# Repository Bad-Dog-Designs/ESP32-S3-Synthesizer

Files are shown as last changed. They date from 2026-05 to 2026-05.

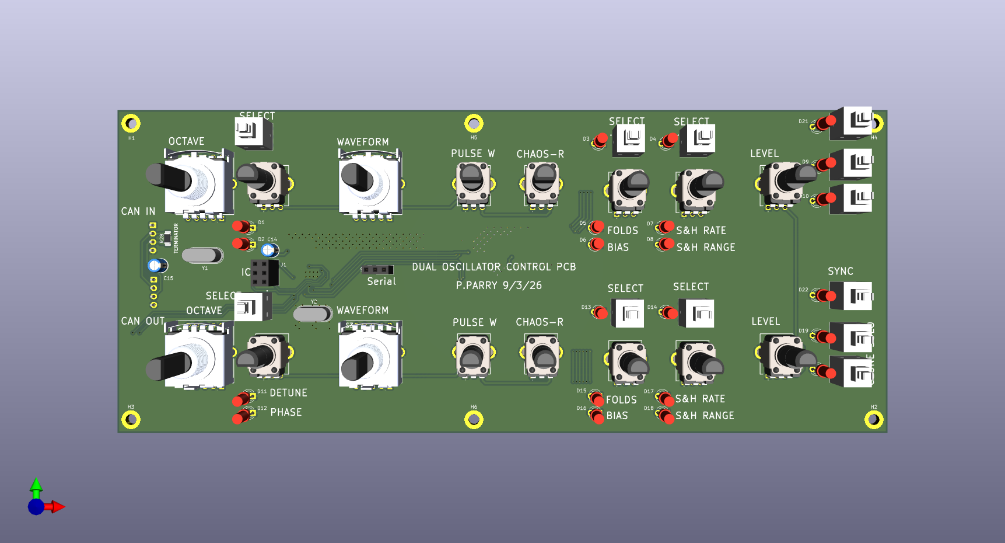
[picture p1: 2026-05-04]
Oscillator_Board/Oscillator_Board.png

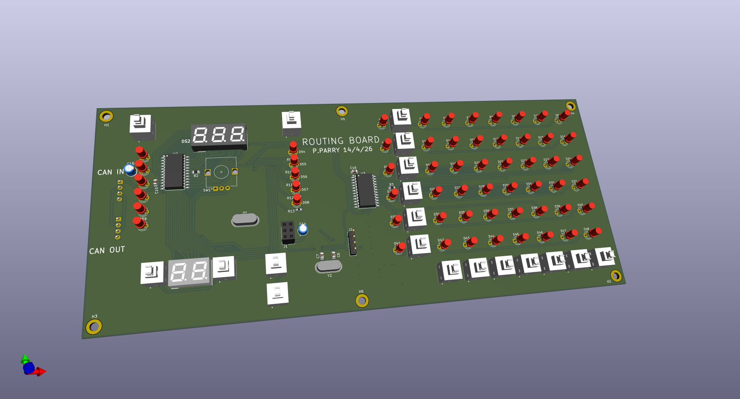
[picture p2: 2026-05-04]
Routing_Board/Routing_Board/Routing_Board.png

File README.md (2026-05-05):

Project overview:
A custom polyphonic synthesizer built around an ESP32-S3 audio engine communicating with multiple ATmega328p control boards via CAN bus at 500kbps. All boards share synth_params.h as the single source of truth for CAN message definitions.
Hardware boards:

ESP32-S3 — audio engine, MIDI input, I2S DAC output, CAN master
Oscillator boards (ATmega328p, up to 4) — dual oscillator control per board, board ID set by hardware jumpers (both open = board 0)
Commons board (ATmega328p) — filter, envelope, LFO, ring mod, play mode controls
Routing board (ATmega328p) — modulation matrix UI, 12 routes, LED matrix display
Patch board (ATmega328p, pending) — SD card patch storage UI, keypad, VFD/starburst display

ESP32-S3 pin assignments:

I2S: GPIO 4(BCK), 5(WS), 6(DOUT)
CAN TX/RX: GPIO 7/8
MIDI RX: GPIO 16
SD card: GPIO 9(CD), 10(CS), 11(MOSI), 12(SCK), 13(MISO)

Current file set (V11.0):

synth_v11.ino — setup(), loop(), task spawn only
synth_engine.h — all type/struct definitions, extern globals, function prototypes
synth_engine.cpp — globals, voice management, oscillator, filter, LFO, FM, audio task
synth_midi.h/.cpp — MIDI byte processing, noteOn/Off, voice allocation
synth_can.h/.cpp — TWAI setup, systemStartup, processCanMessages, sendCanAck
synth_params.h — shared CAN parameter definitions, all boards

Architecture:

Audio runs on Core 1 via audioTask(), CAN+MIDI runs on Core 0 via loop()
portMUX_TYPE voiceMux protects voice array cross-core access
NUM_VOICES_ACTIVE set dynamically from detected oscillator boards at startup (2 per board)
TWAI rx_queue_len=64 to handle full parameter dumps

Voice model:

Up to 8 voices (MAX_VOICES), typically 6 active (3 oscillator boards)
Even voices (0,2,4,6) are FM/sync masters per board pair
Odd voices (1,3,5,7) are FM/sync slaves — can sync to or be FM-modulated by their partner
FM: OSC_A (even) modulates OSC_B (odd) phase. fmEnabled, fmDepth on even voice. fmRatio on odd voice
Hard sync: per-board-pair, not global. syncEnabled only valid on odd voices
Solo: toggle per voice, restricts noteOn to soloed voices only
Clone: copies all timbre params including fmEnabled, fmDepth, fmRatio to all other voices. cloneActive global drives all clone LEDs on all boards simultaneously. Second press clears LEDs, cloned params remain

Signal chain per voice:
S+H → phaseInc | FM phase offset | Oscillator → Wavefold → SVF Filter → × envLevel × level × velocity
Waveforms: SAW, SINE, TRI, PULSE, CHAOS (logistic map), NOISE
Modifiers:

FOLD: post-oscillator waveshaper. foldEnabled, foldAmount (0-1), foldBias (-1 to +1)
S+H: independent pitch randomiser clock. shEnabled, shRate (0.5-40Hz), shRange (1-48 semitones)
FM: fmEnabled, fmDepth (0-1), fmRatio (0.5-8.0)

Play modes: POLY, DUO (half voices per note), UNISON (all voices per note)
Gain scaling by mode: UNISON=1.8f, DUO=2.0f, POLY=4.0f (tuned by ear)
SVF Filter: Low/Band/High pass. cutoffHz, resonance, envAmount (envelope→cutoff), keyTracking. Coefficients updated on each filter parameter change and at noteOn.
Envelope: ADSR. Times stored as float seconds. Coefficients (attackCoeff etc.) computed by updateEnvelopeRates() — must be called at startup and on any time change.
LFOs: 2× LFOs. 4 waveforms (SINE/TRI/CHAOS/S&H). Rate, delay, retrigger. No depth — depth is per-route. RETRIGGER is toggle: each CAN message flips state.
Ring modulator: 4 voice pair options. level, modMute.
Modulation routing (V11 — implementation pending):

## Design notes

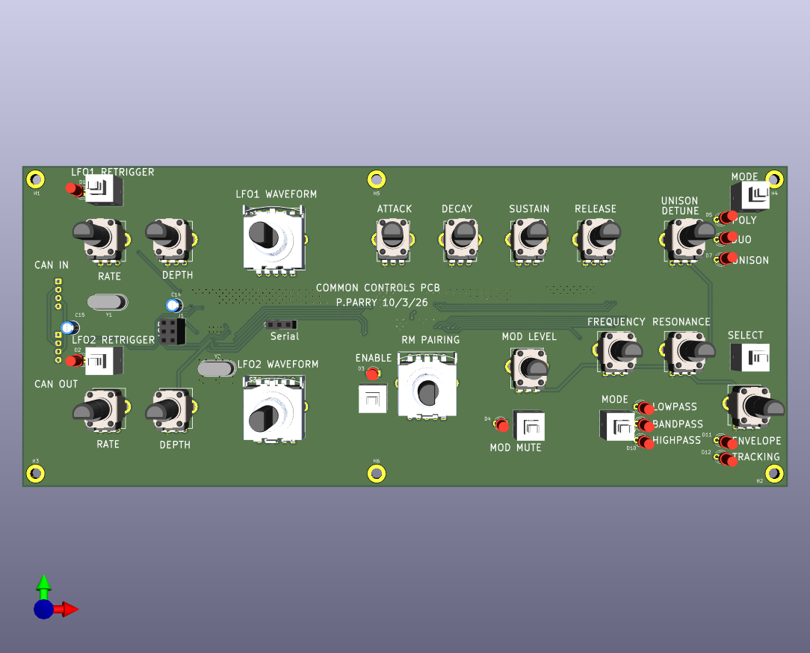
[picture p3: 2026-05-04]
Commons_Board/Commons_Board.png

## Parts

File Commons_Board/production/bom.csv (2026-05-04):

Designator | Footprint | Quantity | Value | LCSC Part #
C1, C2, C6, C7 | 0805 | 4 | 22pf
C10, C11, C3, C4, C5, C8, C9 | 0805 | 7 | 100nF
C12, C13 | 0805 | 2 | 1uF
C14 | CP_Radial_D4.0mm_P2.00mm | 1 | 4.7uF
C15 | CP_Radial_D4.0mm_P2.00mm | 1 | 100uF
C16 | 0805 | 1 | 10nF
D1, D10, D11, D12, D2, D3, D4, D5, D6, D7, D8, D9 | LED_D3.0mm_FlatTop | 12 | LED
FB1 | 0805 | 1 | 10R
IC1 | SOIC127P600X175-8N | 1 | TJA1050T_CM,118
IC2 | SOP65P640X120-20N | 1 | MCP2515T-I_ST
IC3, IC4 | SOIC127P1030X265-28N | 2 | MCP23017-E_SO
J1 | PinSocket_2x03_P2.54mm_Vertical | 1 | ICP Header
J2 | PinSocket_1x03_P2.54mm_Vertical | 1 | Serial Mon
J3 | JST_EH_S4B-EH_1x04_P2.50mm_Horizontal | 1 | Output
J4 | JST_EH_S4B-EH_1x04_P2.50mm_Horizontal | 1 | Input
R1, R25 | 0603 | 2 | 10k
R10, R11, R12, R13, R14, R15, R4, R5, R6, R7, R8, R9 | 0603 | 12 | 330R
R16, R17, R18, R19, R2, R3, R35, R36, R39, R40, R41, R44, R45, R46 | 0603 | 14 | 4k7
R24, R53 | 0603 | 2 | 1k
R28 | 1206 | 1 | 120R
S1 | SR1712F010820F0AN9N027 | 1 | Waveform_0
S10, S11, S5, S6, S7, S8, S9 | TL2285OA | 7 | TL2285OA
S2 | SR1712F010820F0AN9N027 | 1 | Range_0
S3 | SR1712F010820F0AN9N027 | 1 | Waveform_1
U1 | TQFP-32_7x7mm_P0.8mm | 1 | ATmega328P-A
U2 | SSOP-24_5.3x8.2mm_P0.65mm | 1 | CD74HC4067SM
VR1 | RK09K1130AAU | 1 | LFO1_Rate
VR10 | RK09K1130AAU | 1 | Frequency
VR11 | RK09K1130AAU | 1 | Resonance
VR12 | RK09K1130AAU | 1 | Env_Track
VR13 | RK09K1130AAU | 1 | Detune
VR2 | RK09K1130AAU | 1 | LFO1_Depth
VR3 | RK09K1130AAU | 1 | LFO2_Rate
VR4 | RK09K1130AAU | 1 | LFO2_Depth
VR5 | RK09K1130AAU | 1 | Mod_Level
VR6 | RK09K1130AAU | 1 | Attack
VR7 | RK09K1130AAU | 1 | Decay
VR8 | RK09K1130AAU | 1 | Sustain
VR9 | RK09K1130AAU | 1 | Release
Y1 | Crystal_HC49-4H_Vertical | 1 | 8Mhz
Y2 | Crystal_HC49-4H_Vertical | 1 | 16Mhz

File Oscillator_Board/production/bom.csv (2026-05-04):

Designator | Footprint | Quantity | Value | LCSC Part #
C1, C2, C6, C7 | 0805 | 4 | 22pf
C10, C11, C3, C4, C5, C8, C9 | 0805 | 7 | 100nF
C12, C13 | 0805 | 2 | 1uF
C14 | CP_Radial_D4.0mm_P2.00mm | 1 | 4.7uF
C15 | CP_Radial_D4.0mm_P2.00mm | 1 | 100uF
C16 | 0805 | 1 | 10nF
D1, D10, D11, D12, D13, D14, D15, D16, D17, D18, D19, D2, D20, D21, D22, D3, D4, D5, D6, D7, D8, D9 | LED_D3.0mm_FlatTop | 22 | LED
FB1 | 0805 | 1 | 10R
IC1 | SOIC127P600X175-8N | 1 | TJA1050T_CM,118
IC2 | SOP65P640X120-20N | 1 | MCP2515T-I_ST
IC3, IC4 | SOIC127P1030X265-28N | 2 | MCP23017-E_SO
J1 | PinSocket_2x03_P2.54mm_Vertical | 1 | ICP Header
J2 | PinSocket_1x03_P2.54mm_Vertical | 1 | Serial Mon
J3 | JST_EH_S4B-EH_1x04_P2.50mm_Horizontal | 1 | Output
J4 | JST_EH_S4B-EH_1x04_P2.50mm_Horizontal | 1 | Input
R1, R25, R29, R30 | 0603 | 4 | 10k
R10, R11, R12, R13, R14, R15, R16, R17, R18, R19, R20, R21, R22, R23, R26, R27, R4, R5, R6, R7, R8, R9 | 0603 | 22 | 330R
R2, R3, R35, R36, R37, R38, R39, R40, R41, R42, R43, R44, R45, R46, R47, R48, R49, R50, R51, R52 | 0603 | 20 | 4k7
R24, R53 | 0603 | 2 | 1k
R28 | 1206 | 1 | 120R
R31, R32, R33, R34 | 0603 | 4 | Link
S1 | SR1712F010820F0AN9N027 | 1 | Waveform_0
S10, S11, S12, S13, S14, S15, S16, S5, S6, S7, S8, S9 | TL2285OA | 12 | TL2285OA
S2 | SR1712F010820F0AN9N027 | 1 | Range_0
S3 | SR1712F010820F0AN9N027 | 1 | Waveform_1
S4 | SR1712F010820F0AN9N027 | 1 | Range_1
U1 | TQFP-32_7x7mm_P0.8mm | 1 | ATmega328P-A
U2 | SSOP-24_5.3x8.2mm_P0.65mm | 1 | CD74HC4067SM
VR1, VR7 | RK09K1130AAU | 2 | Detune_1
VR10, VR4 | RK09K1130AAU | 2 | Folds_1
VR11, VR5 | RK09K1130AAU | 2 | S&H_1
VR12, VR6 | RK09K1130AAU | 2 | Level_1
VR2, VR8 | RK09K1130AAU | 2 | PulseW_1
VR3, VR9 | RK09K1130AAU | 2 | ChaosR_1
Y1 | Crystal_HC49-4H_Vertical | 1 | 8Mhz
Y2 | Crystal_HC49-4H_Vertical | 1 | 16Mhz

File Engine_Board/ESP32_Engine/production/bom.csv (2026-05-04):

Designator | Footprint | Quantity | Value | LCSC Part #
C1, C10, C16, C18, C2, C23, C6 | 0603 | 7 | 100nF
C11, C12 | 0603 | 2 | 2.2nF
C13, C14 | 0805 | 2 | 2.2uF
C15 | CP_Radial_D4.0mm_P2.00mm | 1 | 100uF
C17, C19, C5, C7 | 0805 | 4 | 10uF
C20 | CP_Radial_D4.0mm_P2.00mm | 1 | 4u7
C21, C22, C8, C9 | 0805 | 4 | 100nF
C3, C4 | 0805 | 2 | 2u2
D1 | D_MELF | 1 | 1N4148
IC2 | SOP65P640X120-20N | 1 | PCM5102AQPWRQ1
IC3 | SOT95P280X100-5N | 1 | 3v3 Digital Reg
IC4 | SOT95P280X100-5N | 1 | 3v3 Analogue Reg
J1 | 5033981892 | 1 | 503398-1892
J2 | Midi_Socket | 1 | Midi in
J3 | JST_EH_S4B-EH_1x04_P2.50mm_Horizontal | 1 | Output
J4 | JST_EH_S4B-EH_1x04_P2.50mm_Horizontal | 1 | Input
J5 | Jack_3.5mm_CUI_SJ1-3533NG_Horizontal | 1 | AudioJack3
R1, R2, R3 | 0603 | 3 | 22R
R10, R6, R7, R8, R9 | 0603 | 5 | 10k
R11 | 0603 | 1 | 220R
R12, R4, R5 | 0603 | 3 | 470R
R28 | 0603 | 1 | 120R
U1 | ESP32_S3 | 1 | ESP32-S3
U2 | DIP-8_W7.62mm | 1 | MCP2562-H-P
U3 | DIP-6_W7.62mm_SMDSocket_SmallPads | 1 | H11L1

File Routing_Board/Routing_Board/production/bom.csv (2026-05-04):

Designator | Footprint | Quantity | Value | LCSC Part #
C1, C2, C6, C7 | 0805 | 4 | 22pf
C10, C11, C16, C3, C4, C5, C8, C9 | 0805 | 8 | 100nF
C12, C13 | 0805 | 2 | 1uF
C14 | CP_Radial_D4.0mm_P2.00mm | 1 | 4.7uF
C15 | CP_Radial_D4.0mm_P2.00mm | 1 | 100uF
D1, D10, D11, D12, D13, D14, D15, D16, D17, D18, D19, D2, D20, D21, D22, D23, D24, D25, D26, D27, D28, D29, D3, D30, D31, D32, D33, D34, D35, D36, D37, D38, D39, D4, D40, D41, D42, D43, D44, D45, D46, D47, D48, D49, D5, D50, D51, D52, D53, D54, D55, D56, D57, D58, D59, D6, D7, D8, D9 | LED_D3.0mm_FlatTop | 59 | LED
DS1 | DIPS762W50P254L1502H635Q10N | 1 | LTD-2701JD
DS2 | DIPS762W45P254L2253H610Q12N | 1 | LDT-N2804RI
IC1 | SOIC127P600X175-8N | 1 | TJA1050T_CM,118
IC2 | SOP65P640X120-20N | 1 | MCP2515T-I_ST
IC3, IC4 | SOIC127P1030X265-28N | 2 | MCP23017-E_SO
J1 | PinSocket_2x03_P2.54mm_Vertical | 1 | ICP Header
J2 | PinHeader_1x04_P2.54mm_Vertical | 1 | Diagnostic
J3 | JST_EH_S4B-EH_1x04_P2.50mm_Horizontal | 1 | Output
J4 | JST_EH_S4B-EH_1x04_P2.50mm_Horizontal | 1 | Input
R1, R25 | 0603 | 2 | 10k
R10, R11, R12, R13, R18, R4, R5, R6, R7, R8, R9 | 0603 | 11 | 330R
R14, R15 | 0805 | 2 | 10k
R16, R17 | 0805 | 2 | 4k7
R2, R3 | 0805 | 2 | 22k
R24 | 0603 | 1 | 1k
R28 | 1206 | 1 | 120R
S1, S10, S11, S12, S13, S14, S15, S16, S17, S18, S19, S2, S3, S4, S5, S6, S7, S8, S9 | TL2285OA | 19 | TL2285OA
SW1 | RotaryEncoder_Alps_EC12E_Vertical_H20mm | 1 | RotaryEncoder
U1 | TQFP-32_7x7mm_P0.8mm | 1 | ATmega328P-A
U2, U3 | SOIC-24W_7.5x15.4mm_P1.27mm | 2 | MAX7219
Y1 | Crystal_HC49-4H_Vertical | 1 | 8Mhz
Y2 | Crystal_HC49-4H_Vertical | 1 | 16Mhz

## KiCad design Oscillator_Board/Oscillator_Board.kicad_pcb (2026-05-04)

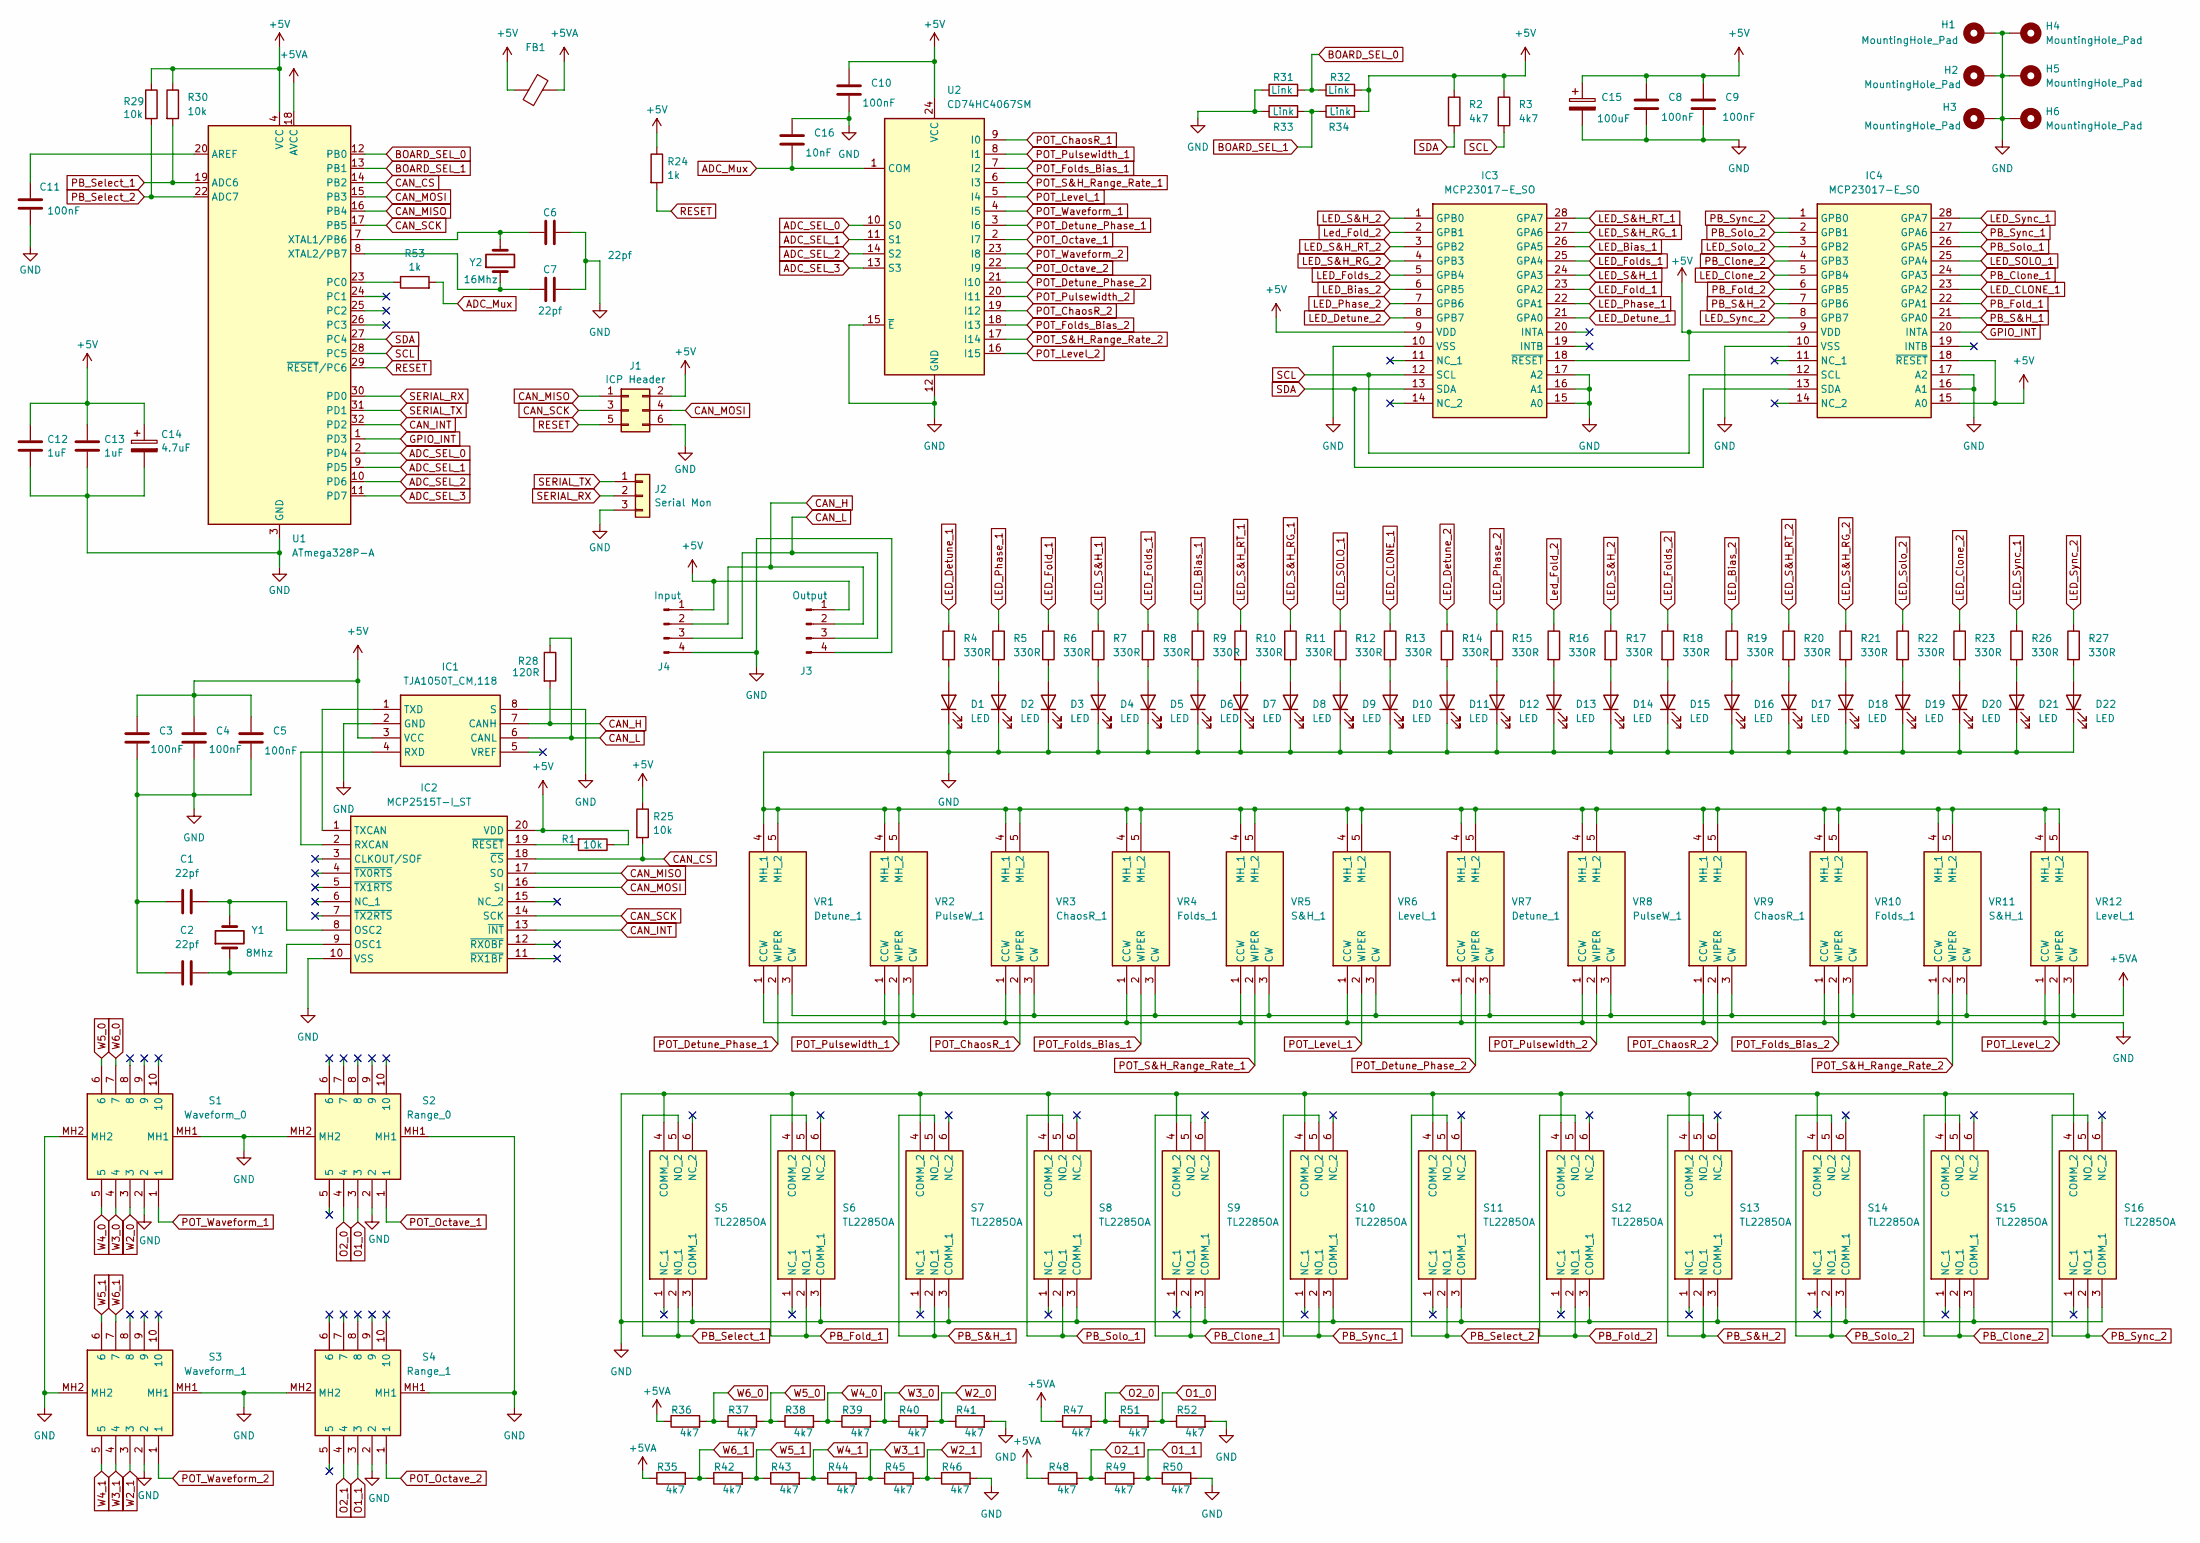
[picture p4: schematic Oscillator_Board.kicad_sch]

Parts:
C1, C2, C6, C7: 22pf; C_0805_2012Metric_Pad1.18x1.45mm_HandSolder
C3, C4, C5, C8, C9, C10, C11: 100nF; C_0805_2012Metric_Pad1.18x1.45mm_HandSolder
C12, C13: 1uF; C_0805_2012Metric_Pad1.18x1.45mm_HandSolder
C14: 4.7uF; CP_Radial_D4.0mm_P2.00mm
C15: 100uF; CP_Radial_D4.0mm_P2.00mm
C16: 10nF; C_0805_2012Metric_Pad1.18x1.45mm_HandSolder
D1, D2, D3, D4, D5, D6, D7, D8, D9, D10, D11, D12, D13, D14, D15, D16, D17, D18, D19, D20, D21, D22: LED; LED_D3.0mm_FlatTop
FB1: 10R; R_0805_2012Metric_Pad1.20x1.40mm_HandSolder
H1, H2, H3, H4, H5, H6: MountingHole_Pad; MountingHole_3.2mm_M3_DIN965_Pad
IC1: TJA1050T_CM,118; SOIC127P600X175-8N; Mouser Part Number 771-TJA1050T/CM118
IC2: MCP2515T-I_ST; SOP65P640X120-20N; Mouser Part Number 579-MCP2515T-I/ST
IC3, IC4: MCP23017-E_SO; SOIC127P1030X265-28N; Mouser Part Number 579-MCP23017-E/SO
J1: ICP Header; PinSocket_2x03_P2.54mm_Vertical
J2: Serial Mon; PinSocket_1x03_P2.54mm_Vertical
J3: Output; JST_EH_S4B-EH_1x04_P2.50mm_Horizontal
J4: Input; JST_EH_S4B-EH_1x04_P2.50mm_Horizontal
R1, R25, R29, R30: 10k; R_0603_1608Metric_Pad0.98x0.95mm_HandSolder
R2, R3, R35, R36, R37, R38, R39, R40, R41, R42, R43, R44, R45, R46, R47, R48, R49, R50, R51, R52: 4k7; R_0603_1608Metric_Pad0.98x0.95mm_HandSolder
R4, R5, R6, R7, R8, R9, R10, R11, R12, R13, R14, R15, R16, R17, R18, R19, R20, R21, R22, R23, R26, R27: 330R; R_0603_1608Metric_Pad0.98x0.95mm_HandSolder
R24, R53: 1k; R_0603_1608Metric_Pad0.98x0.95mm_HandSolder
R28: 120R; R_1206_3216Metric_Pad1.30x1.75mm_HandSolder
R31, R32, R33, R34: Link; R_0603_1608Metric_Pad0.98x0.95mm_HandSolder
S1: Waveform_0; SR1712F010820F0AN9N027; Mouser Part Number 105-SR1712F-18NS
S2: Range_0; SR1712F010820F0AN9N027; Mouser Part Number 105-SR1712F-18NS
S3: Waveform_1; SR1712F010820F0AN9N027; Mouser Part Number 105-SR1712F-18NS
S4: Range_1; SR1712F010820F0AN9N027; Mouser Part Number 105-SR1712F-18NS
S5, S6, S7, S8, S9, S10, S11, S12, S13, S14, S15, S16: TL2285OA; Mouser Part Number 612-TL2285OA
U1: ATmega328P-A; TQFP-32_7x7mm_P0.8mm
U2: CD74HC4067SM; SSOP-24_5.3x8.2mm_P0.65mm
VR1, VR7: Detune_1; RK09K1130AAU; Mouser Part Number 688-RK09K1130AAU
VR2, VR8: PulseW_1; RK09K1130AAU; Mouser Part Number 688-RK09K1130AAU
VR3, VR9: ChaosR_1; RK09K1130AAU; Mouser Part Number 688-RK09K1130AAU
VR4, VR10: Folds_1; RK09K1130AAU; Mouser Part Number 688-RK09K1130AAU
VR5, VR11: S&H_1; RK09K1130AAU; Mouser Part Number 688-RK09K1130AAU
VR6, VR12: Level_1; RK09K1130AAU; Mouser Part Number 688-RK09K1130AAU
Y1: 8Mhz; Crystal_HC49-4H_Vertical
Y2: 16Mhz; Crystal_HC49-4H_Vertical

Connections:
+5V: C3.1, C4.1, C5.1, C8.1, C9.1, C10.1, C12.1, C13.1, C14.1, C15.1, FB1.1, IC1.3 (VCC), IC2.20 (VDD), IC3.9 (VDD), IC3.18 (~RESET), IC4.9 (VDD), IC4.15 (A0), IC4.18 (~RESET), J1.2, J3.1, J4.1, R1.1, R2.1, R3.1, R24.1, R25.1, R29.1, R30.1, R32.2, R34.2, U1.4 (VCC), U1.6 (VCC), U2.24 (VCC)
+5VA: FB1.2, R35.1, R36.1, R47.1, R48.1, U1.18 (AVCC), VR1.3 (CW), VR2.3 (CW), VR3.3 (CW), VR4.3 (CW), VR5.3 (CW), VR6.3 (CW), VR7.3 (CW), VR8.3 (CW), VR9.3 (CW), VR10.3 (CW), VR11.3 (CW), VR12.3 (CW)
ADC_Mux: C16.2, R53.2, U2.1 (COM)
ADC_SEL_0: U1.2 (PD4), U2.10 (S0)
ADC_SEL_1: U1.9 (PD5), U2.11 (S1)
ADC_SEL_2: U1.10 (PD6), U2.14 (S2)
ADC_SEL_3: U1.11 (PD7), U2.13 (S3)
BOARD_SEL_0: R31.2, R32.1, U1.12 (PB0)
BOARD_SEL_1: R33.2, R34.1, U1.13 (PB1)
CAN_CS: IC2.18 (~CS), R25.2, U1.14 (PB2)
CAN_H: IC1.7 (CANH), J3.2, J4.2, R28.2
CAN_INT: IC2.13 (~INT), U1.32 (PD2)
CAN_L: IC1.6 (CANL), J3.3, J4.3, R28.1
CAN_MISO: IC2.17 (SO), J1.1, U1.16 (PB4)
CAN_MOSI: IC2.16 (SI), J1.4, U1.15 (PB3)
CAN_SCK: IC2.14 (SCK), J1.3, U1.17 (PB5)
GND: C1.1, C2.1, C3.2, C4.2, C5.2, C6.2, C7.2, C8.2, C9.2, C10.2, C11.2, C12.2, C13.2, C14.2, C15.2, C16.1, D1.1 (K), D2.1 (K), D3.1 (K), D4.1 (K), D5.1 (K), D6.1 (K), D7.1 (K), D8.1 (K), D9.1 (K), D10.1 (K), D11.1 (K), D12.1 (K), D13.1 (K), D14.1 (K), D15.1 (K), D16.1 (K), D17.1 (K), D18.1 (K), D19.1 (K), D20.1 (K), D21.1 (K), D22.1 (K), H1.1, H2.1, H3.1, H4.1, H5.1, H6.1, IC1.2 (GND), IC1.8 (S), IC2.10 (VSS), IC3.10 (VSS), IC3.15 (A0), IC3.16 (A1), IC3.17 (A2), IC4.10 (VSS), IC4.16 (A1), IC4.17 (A2), J1.6, J2.3, J3.4, J4.4, R31.1, R33.1, R41.2, R46.2, R50.2, R52.2, S1.2, S1.MH1, S1.MH2, S2.2, S2.MH1, S2.MH2, S3.2, S3.MH1, S3.MH2, S4.2, S4.MH1, S4.MH2, S5.3 (COMM_1), S5.4 (COMM_2), S6.3 (COMM_1), S6.4 (COMM_2), S7.3 (COMM_1), S7.4 (COMM_2), S8.3 (COMM_1), S8.4 (COMM_2), S9.3 (COMM_1), S9.4 (COMM_2), S10.3 (COMM_1), S10.4 (COMM_2), S11.3 (COMM_1), S11.4 (COMM_2), S12.3 (COMM_1), S12.4 (COMM_2), S13.3 (COMM_1), S13.4 (COMM_2), S14.3 (COMM_1), S14.4 (COMM_2), S15.3 (COMM_1), S15.4 (COMM_2), S16.3 (COMM_1), S16.4 (COMM_2), U1.3 (GND), U1.5 (GND), U1.21 (GND), U2.12 (GND), U2.15 (~E), VR1.1 (CCW), VR1.4 (MH_1), VR1.5 (MH_2), VR2.1 (CCW), VR2.4 (MH_1), VR2.5 (MH_2), VR3.1 (CCW), VR3.4 (MH_1), VR3.5 (MH_2), VR4.1 (CCW), VR4.4 (MH_1), VR4.5 (MH_2), VR5.1 (CCW), VR5.4 (MH_1), VR5.5 (MH_2), VR6.1 (CCW), VR6.4 (MH_1), VR6.5 (MH_2), VR7.1 (CCW), VR7.4 (MH_1), VR7.5 (MH_2), VR8.1 (CCW), VR8.4 (MH_1), VR8.5 (MH_2), VR9.1 (CCW), VR9.4 (MH_1), VR9.5 (MH_2), VR10.1 (CCW), VR10.4 (MH_1), VR10.5 (MH_2), VR11.1 (CCW), VR11.4 (MH_1), VR11.5 (MH_2), VR12.1 (CCW), VR12.4 (MH_1), VR12.5 (MH_2)
GPIO_INT: IC4.20 (INTA), U1.1 (PD3)
LED_Bias_1: IC3.26 (GPA5), R9.1
LED_Bias_2: IC3.6 (GPB5), R19.1
LED_CLONE_1: IC4.23 (GPA2), R13.1
LED_Clone_2: IC4.5 (GPB4), R23.1
LED_Detune_1: IC3.21 (GPA0), R4.1
LED_Detune_2: IC3.8 (GPB7), R14.1
LED_Fold_1: IC3.23 (GPA2), R6.1
LED_Folds_1: IC3.25 (GPA4), R8.1
LED_Folds_2: IC3.5 (GPB4), R18.1
LED_Phase_1: IC3.22 (GPA1), R5.1
LED_Phase_2: IC3.7 (GPB6), R15.1
LED_S&H_1: IC3.24 (GPA3), R7.1
LED_S&H_2: IC3.1 (GPB0), R17.1
LED_S&H_RG_1: IC3.27 (GPA6), R11.1
LED_S&H_RG_2: IC3.4 (GPB3), R21.1
LED_S&H_RT_1: IC3.28 (GPA7), R10.1
LED_S&H_RT_2: IC3.3 (GPB2), R20.1
LED_SOLO_1: IC4.25 (GPA4), R12.1
LED_Solo_2: IC4.3 (GPB2), R22.1
LED_Sync_1: IC4.28 (GPA7), R26.1
LED_Sync_2: IC4.8 (GPB7), R27.1
Led_Fold_2: IC3.2 (GPB1), R16.1
unnamed: D1.2 (A), R4.2
unnamed: D2.2 (A), R5.2
unnamed: D3.2 (A), R6.2
unnamed: D4.2 (A), R7.2
unnamed: D5.2 (A), R8.2
unnamed: D6.2 (A), R9.2
unnamed: D7.2 (A), R10.2
unnamed: D8.2 (A), R11.2
unnamed: D9.2 (A), R12.2
unnamed: D10.2 (A), R13.2
unnamed: D11.2 (A), R14.2
unnamed: D12.2 (A), R15.2
unnamed: D13.2 (A), R16.2
unnamed: D14.2 (A), R17.2
unnamed: D15.2 (A), R18.2
unnamed: D16.2 (A), R19.2
unnamed: D17.2 (A), R20.2
unnamed: D18.2 (A), R21.2
unnamed: D19.2 (A), R22.2
unnamed: D20.2 (A), R23.2
unnamed: D21.2 (A), R26.2
unnamed: D22.2 (A), R27.2
unnamed: IC1.4 (RXD), IC2.2 (RXCAN)
unnamed: IC1.1 (TXD), IC2.1 (TXCAN)
unnamed: C2.2, IC2.9 (OSC1), Y1.1
unnamed: C1.2, IC2.8 (OSC2), Y1.2
unnamed: IC2.19 (~RESET), R1.2
unnamed: C11.1, U1.20 (AREF)
unnamed: R53.1, U1.23 (PC0)
unnamed: C6.1, U1.7 (XTAL1/PB6), Y2.2
unnamed: C7.1, U1.8 (XTAL2/PB7), Y2.1
O1_0: R51.2, R52.1, S2.3
O1_1: R49.2, R50.1, S4.3
O2_0: R47.2, R51.1, S2.4
O2_1: R48.2, R49.1, S4.4
PB_Clone_1: IC4.24 (GPA3), S9.2 (NO_1), S9.5 (NO_2)
PB_Clone_2: IC4.4 (GPB3), S15.2 (NO_1), S15.5 (NO_2)
PB_Fold_1: IC4.22 (GPA1), S6.2 (NO_1), S6.5 (NO_2)
PB_Fold_2: IC4.6 (GPB5), S12.2 (NO_1), S12.5 (NO_2)
PB_S&H_1: IC4.21 (GPA0), S7.2 (NO_1), S7.5 (NO_2)
PB_S&H_2: IC4.7 (GPB6), S13.2 (NO_1), S13.5 (NO_2)
PB_Select_1: R30.2, S5.2 (NO_1), S5.5 (NO_2), U1.19 (ADC6)
PB_Select_2: R29.2, S11.2 (NO_1), S11.5 (NO_2), U1.22 (ADC7)
PB_Solo_1: IC4.26 (GPA5), S8.2 (NO_1), S8.5 (NO_2)
PB_Solo_2: IC4.2 (GPB1), S14.2 (NO_1), S14.5 (NO_2)
PB_Sync_1: IC4.27 (GPA6), S10.2 (NO_1), S10.5 (NO_2)
PB_Sync_2: IC4.1 (GPB0), S16.2 (NO_1), S16.5 (NO_2)
POT_ChaosR_1: U2.9 (I0), VR3.2 (WIPER)
POT_ChaosR_2: U2.19 (I12), VR9.2 (WIPER)
POT_Detune_Phase_1: U2.3 (I6), VR1.2 (WIPER)
POT_Detune_Phase_2: U2.21 (I10), VR7.2 (WIPER)
POT_Folds_Bias_1: U2.7 (I2), VR4.2 (WIPER)
POT_Folds_Bias_2: U2.18 (I13), VR10.2 (WIPER)
POT_Level_1: U2.5 (I4), VR6.2 (WIPER)
POT_Level_2: U2.16 (I15), VR12.2 (WIPER)
POT_Octave_1: S2.1, U2.2 (I7)
POT_Octave_2: S4.1, U2.22 (I9)
POT_Pulsewidth_1: U2.8 (I1), VR2.2 (WIPER)
POT_Pulsewidth_2: U2.20 (I11), VR8.2 (WIPER)
POT_S&H_Range_Rate_1: U2.6 (I3), VR5.2 (WIPER)
POT_S&H_Range_Rate_2: U2.17 (I14), VR11.2 (WIPER)
POT_Waveform_1: S1.1, U2.4 (I5)
POT_Waveform_2: S3.1, U2.23 (I8)
RESET: J1.5, R24.2, U1.29 (~RESET/PC6)
SCL: IC3.12 (SCL), IC4.12 (SCL), R3.2, U1.28 (PC5)
SDA: IC3.13 (SDA), IC4.13 (SDA), R2.2, U1.27 (PC4)
SERIAL_RX: J2.2, U1.30 (PD0)
SERIAL_TX: J2.1, U1.31 (PD1)
W2_0: R40.2, R41.1, S1.3
W2_1: R45.2, R46.1, S3.3
W3_0: R39.2, R40.1, S1.4
W3_1: R44.2, R45.1, S3.4
W4_0: R38.2, R39.1, S1.5
W4_1: R43.2, R44.1, S3.5
W5_0: R37.2, R38.1, S1.6
W5_1: R42.2, R43.1, S3.6
W6_0: R36.2, R37.1, S1.7
W6_1: R35.2, R42.1, S3.7

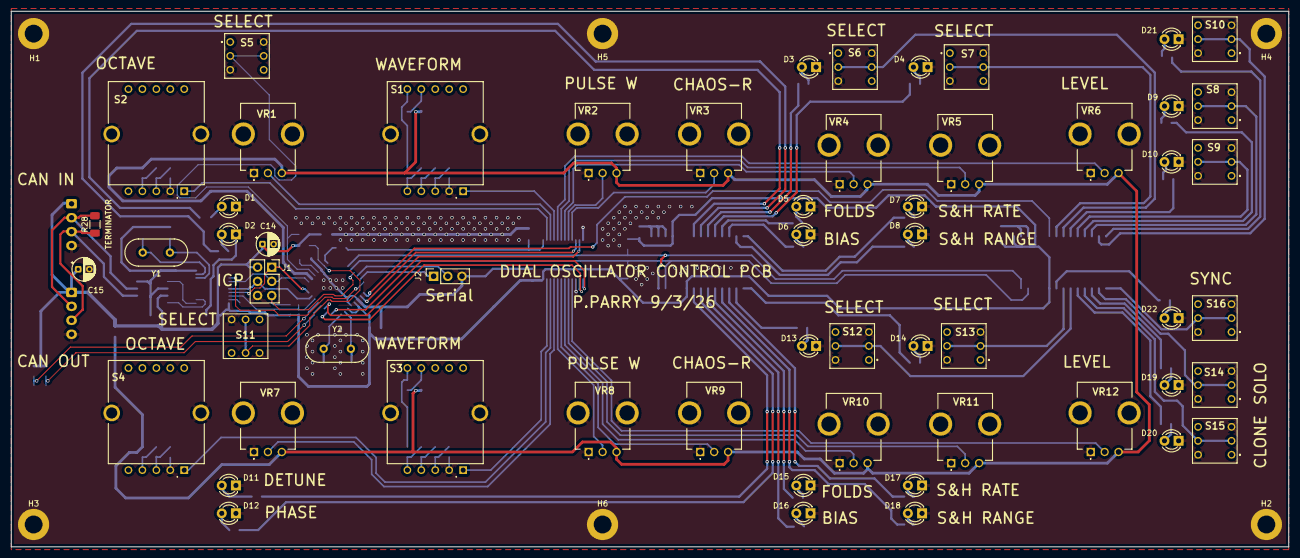
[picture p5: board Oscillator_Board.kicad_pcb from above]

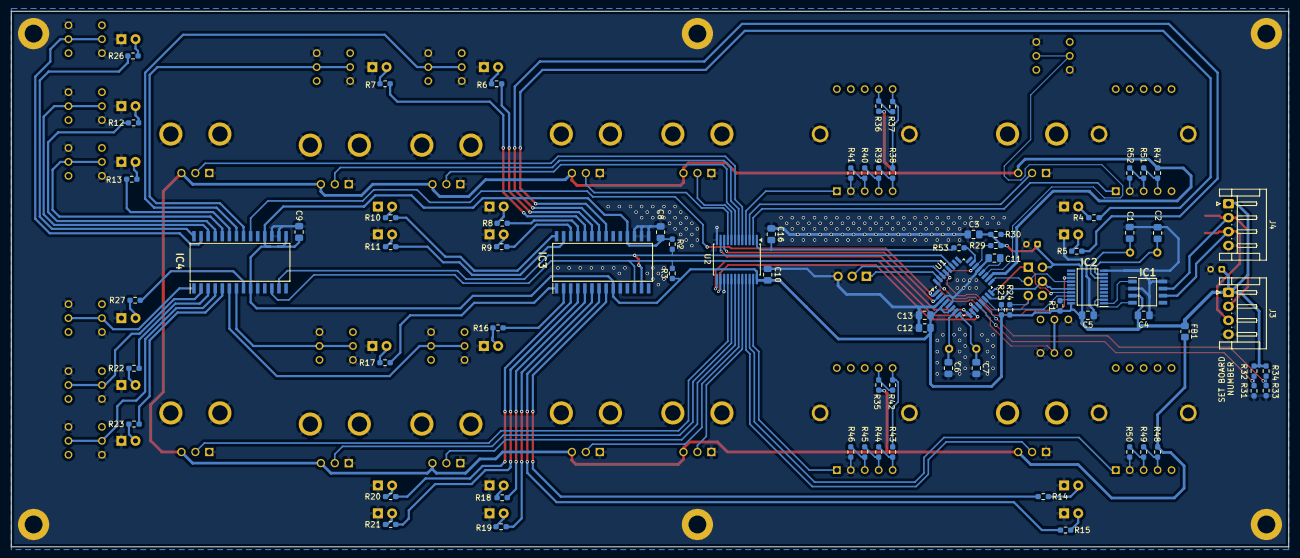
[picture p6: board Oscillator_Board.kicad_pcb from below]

Board: 2 copper layers, 229.0 x 96.0 mm, 138 parts (75 on the bottom side), 118 nets.

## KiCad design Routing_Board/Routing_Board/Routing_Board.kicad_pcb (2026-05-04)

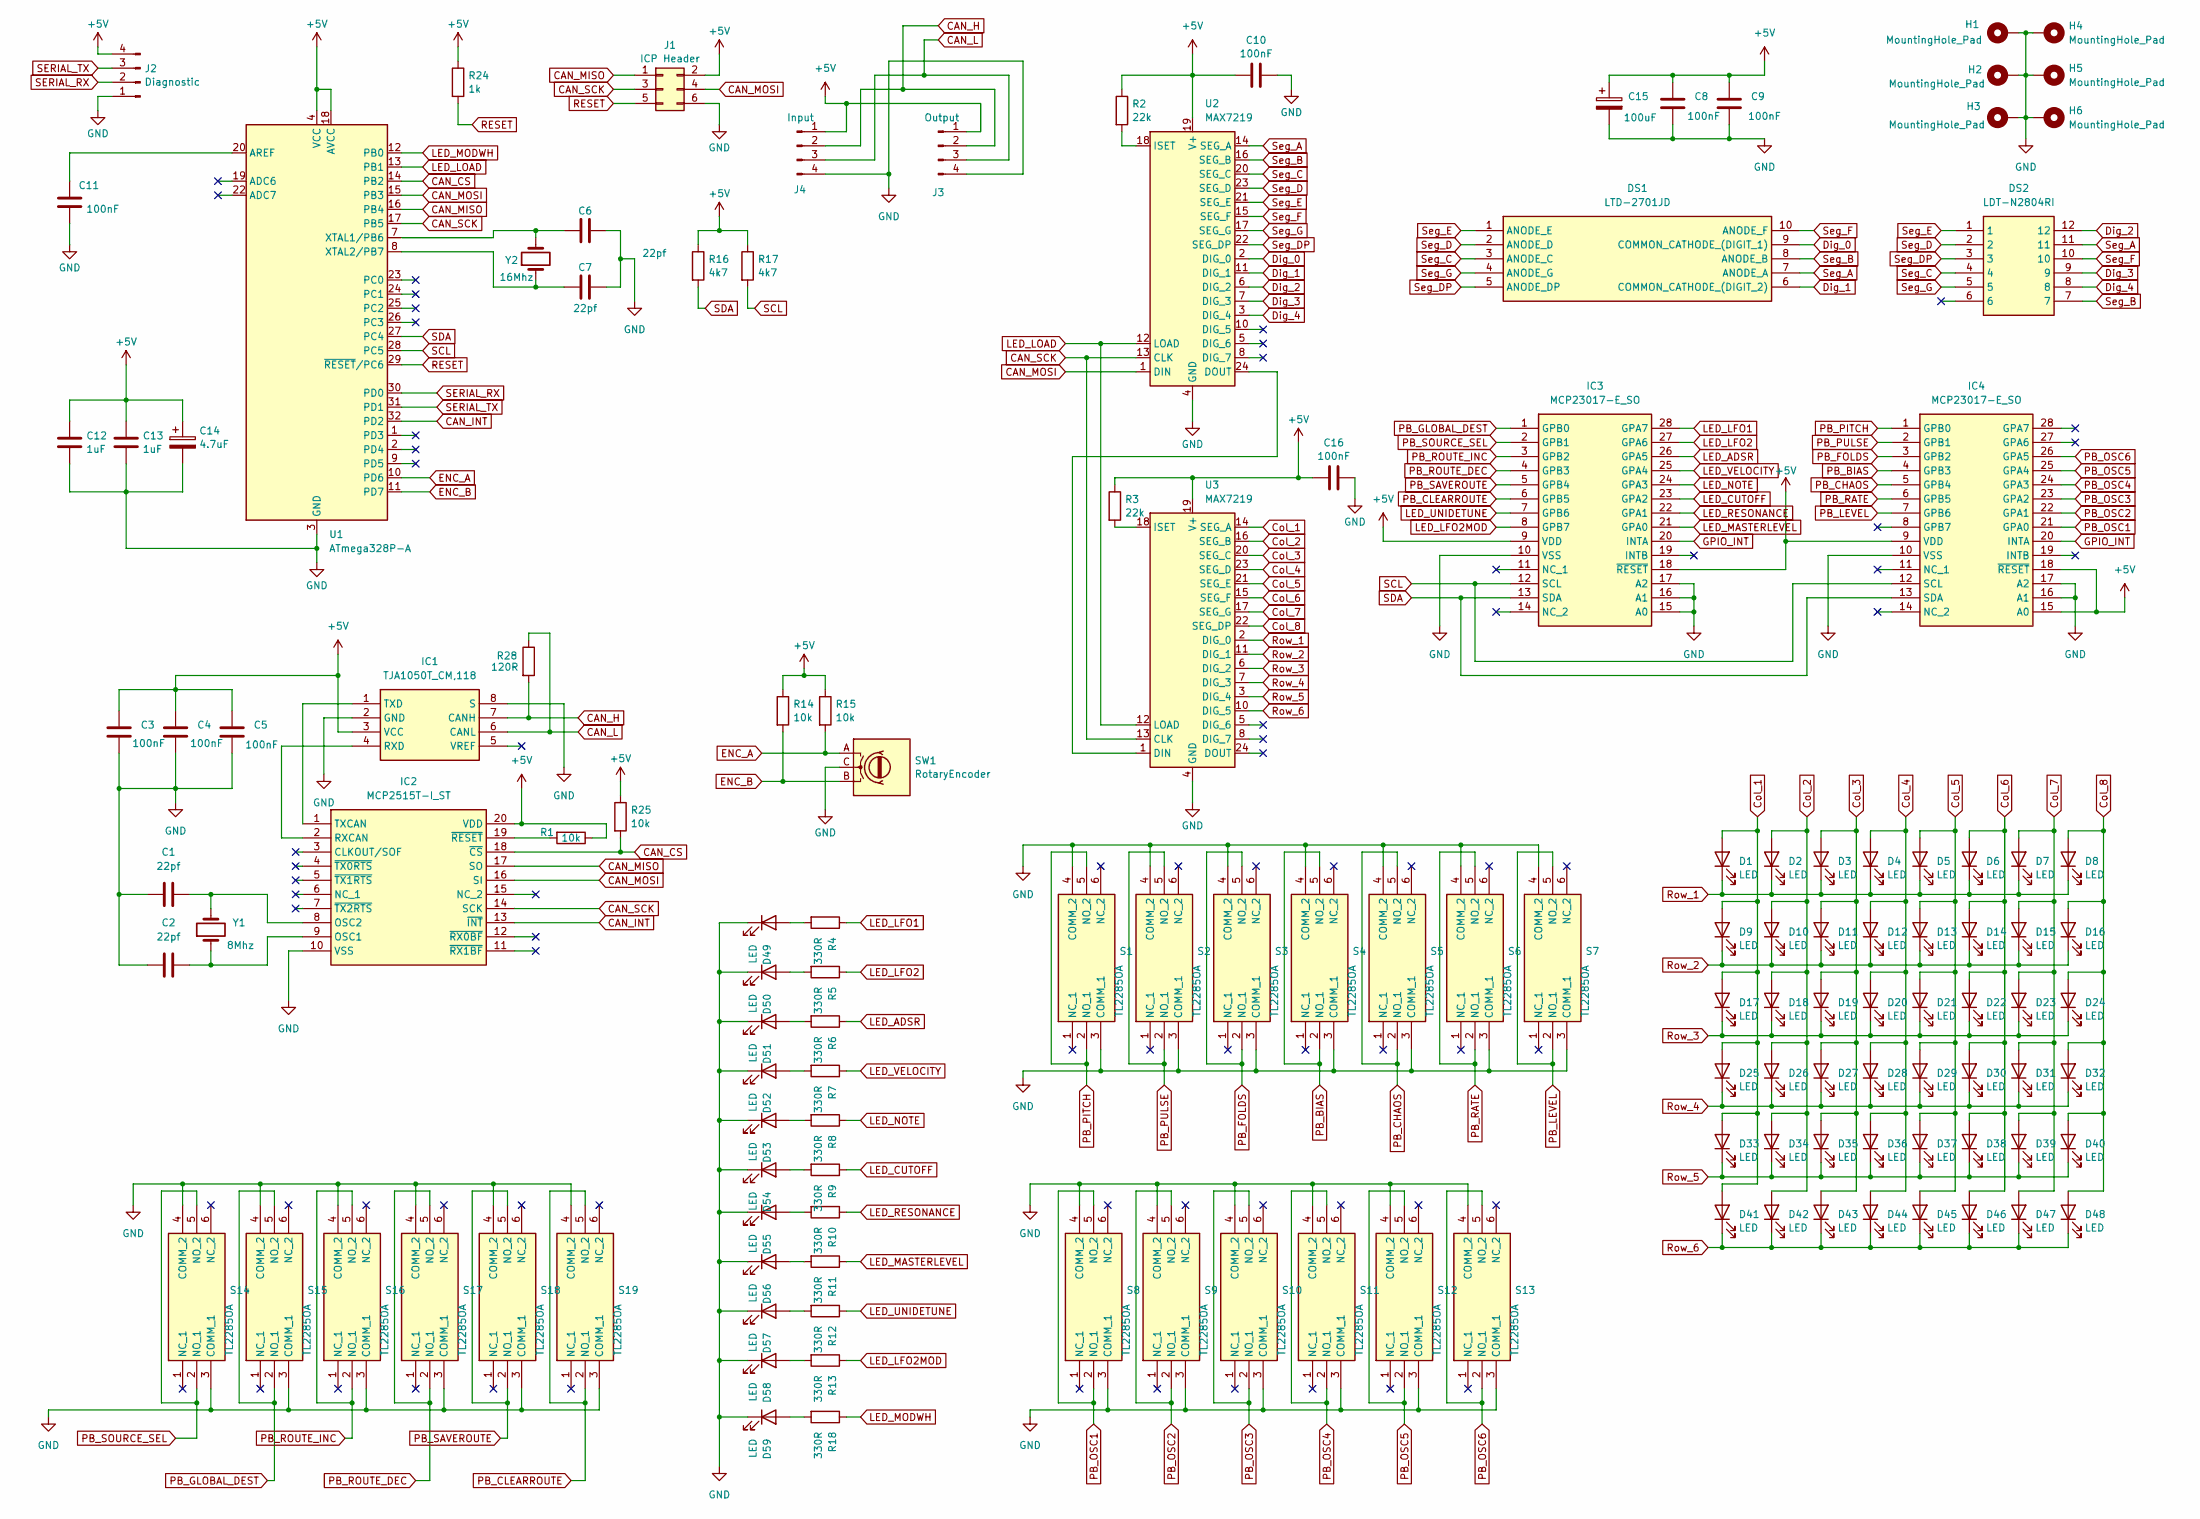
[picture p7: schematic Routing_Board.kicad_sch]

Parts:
C1, C2, C6, C7: 22pf; C_0805_2012Metric_Pad1.18x1.45mm_HandSolder
C3, C4, C5, C8, C9, C10, C11, C16: 100nF; C_0805_2012Metric_Pad1.18x1.45mm_HandSolder
C12, C13: 1uF; C_0805_2012Metric_Pad1.18x1.45mm_HandSolder
C14: 4.7uF; CP_Radial_D4.0mm_P2.00mm
C15: 100uF; CP_Radial_D4.0mm_P2.00mm
D1, D2, D3, D4, D5, D6, D7, D8, D9, D10, D11, D12, D13, D14, D15, D16, D17, D18, D19, D20, D21, D22, D23, D24, D25, D26, D27, D28, D29, D30, D31, D32, D33, D34, D35, D36, D37, D38, D39, D40, D41, D42, D43, D44, D45, D46, D47, D48, D49, D50, D51, D52, D53, D54, D55, D56, D57, D58, D59: LED; LED_D3.0mm_FlatTop
DS1: LTD-2701JD; DIPS762W50P254L1502H635Q10N; Mouser Part Number 859-LTD-2701JD
DS2: LDT-N2804RI; DIPS762W45P254L2253H610Q12N; Mouser Part Number 696-LDT-N2804RI
H1, H2, H3, H4, H5, H6: MountingHole_Pad; MountingHole_3.2mm_M3_DIN965_Pad
IC1: TJA1050T_CM,118; SOIC127P600X175-8N; Mouser Part Number 771-TJA1050T/CM118
IC2: MCP2515T-I_ST; SOP65P640X120-20N; Mouser Part Number 579-MCP2515T-I/ST
IC3, IC4: MCP23017-E_SO; SOIC127P1030X265-28N; Mouser Part Number 579-MCP23017-E/SO
J1: ICP Header; PinSocket_2x03_P2.54mm_Vertical
J2: Diagnostic; PinHeader_1x04_P2.54mm_Vertical
J3: Output; JST_EH_S4B-EH_1x04_P2.50mm_Horizontal
J4: Input; JST_EH_S4B-EH_1x04_P2.50mm_Horizontal
R1, R25: 10k; R_0603_1608Metric_Pad0.98x0.95mm_HandSolder
R2, R3: 22k; R_0805_2012Metric_Pad1.20x1.40mm_HandSolder
R4, R5, R6, R7, R8, R9, R10, R11, R12, R13, R18: 330R; R_0603_1608Metric_Pad0.98x0.95mm_HandSolder
R14, R15: 10k; R_0805_2012Metric_Pad1.20x1.40mm_HandSolder
R16, R17: 4k7; R_0805_2012Metric_Pad1.20x1.40mm_HandSolder
R24: 1k; R_0603_1608Metric_Pad0.98x0.95mm_HandSolder
R28: 120R; R_1206_3216Metric_Pad1.30x1.75mm_HandSolder
S1, S2, S3, S4, S5, S6, S7, S8, S9, S10, S11, S12, S13, S14, S15, S16, S17, S18, S19: TL2285OA; Mouser Part Number 612-TL2285OA
SW1: RotaryEncoder; RotaryEncoder_Alps_EC12E_Vertical_H20mm
U1: ATmega328P-A; TQFP-32_7x7mm_P0.8mm
U2, U3: MAX7219; SOIC-24W_7.5x15.4mm_P1.27mm
Y1: 8Mhz; Crystal_HC49-4H_Vertical
Y2: 16Mhz; Crystal_HC49-4H_Vertical

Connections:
+5V: C3.1, C4.1, C5.1, C8.1, C9.1, C10.1, C12.1, C13.1, C14.1, C15.1, C16.1, IC1.3 (VCC), IC2.20 (VDD), IC3.9 (VDD), IC3.18 (~RESET), IC4.9 (VDD), IC4.15 (A0), IC4.18 (~RESET), J1.2, J2.4, J3.1, J4.1, R1.1, R2.1, R3.1, R14.1, R15.1, R16.1, R17.1, R24.1, R25.1, U1.4 (VCC), U1.6 (VCC), U1.18 (AVCC), U2.19 (V+), U3.19 (V+)
CAN_CS: IC2.18 (~CS), R25.2, U1.14 (PB2)
CAN_H: IC1.7 (CANH), J3.2, J4.2, R28.2
CAN_INT: IC2.13 (~INT), U1.32 (PD2)
CAN_L: IC1.6 (CANL), J3.3, J4.3, R28.1
CAN_MISO: IC2.17 (SO), J1.1, U1.16 (PB4)
CAN_MOSI: IC2.16 (SI), J1.4, U1.15 (PB3), U2.1 (DIN)
CAN_SCK: IC2.14 (SCK), J1.3, U1.17 (PB5), U2.13 (CLK), U3.13 (CLK)
Col_1: D1.2 (A), D9.2 (A), D17.2 (A), D25.2 (A), D33.2 (A), D41.2 (A), U3.14 (SEG_A)
Col_2: D2.2 (A), D10.2 (A), D18.2 (A), D26.2 (A), D34.2 (A), D42.2 (A), U3.16 (SEG_B)
Col_3: D3.2 (A), D11.2 (A), D19.2 (A), D27.2 (A), D35.2 (A), D43.2 (A), U3.20 (SEG_C)
Col_4: D4.2 (A), D12.2 (A), D20.2 (A), D28.2 (A), D36.2 (A), D44.2 (A), U3.23 (SEG_D)
Col_5: D5.2 (A), D13.2 (A), D21.2 (A), D29.2 (A), D37.2 (A), D45.2 (A), U3.21 (SEG_E)
Col_6: D6.2 (A), D14.2 (A), D22.2 (A), D30.2 (A), D38.2 (A), D46.2 (A), U3.15 (SEG_F)
Col_7: D7.2 (A), D15.2 (A), D23.2 (A), D31.2 (A), D39.2 (A), D47.2 (A), U3.17 (SEG_G)
Col_8: D8.2 (A), D16.2 (A), D24.2 (A), D32.2 (A), D40.2 (A), D48.2 (A), U3.22 (SEG_DP)
Dig_0: DS1.9 (COMMON_CATHODE_(DIGIT_1)), U2.2 (DIG_0)
Dig_1: DS1.6 (COMMON_CATHODE_(DIGIT_2)), U2.11 (DIG_1)
Dig_2: DS2.12, U2.6 (DIG_2)
Dig_3: DS2.9, U2.7 (DIG_3)
Dig_4: DS2.8, U2.3 (DIG_4)
ENC_A: R15.2, SW1.A, U1.10 (PD6)
ENC_B: R14.2, SW1.B, U1.11 (PD7)
GND: C1.1, C2.1, C3.2, C4.2, C5.2, C6.2, C7.2, C8.2, C9.2, C10.2, C11.2, C12.2, C13.2, C14.2, C15.2, C16.2, D49.1 (K), D50.1 (K), D51.1 (K), D52.1 (K), D53.1 (K), D54.1 (K), D55.1 (K), D56.1 (K), D57.1 (K), D58.1 (K), D59.1 (K), H1.1, H2.1, H3.1, H4.1, H5.1, H6.1, IC1.2 (GND), IC1.8 (S), IC2.10 (VSS), IC3.10 (VSS), IC3.15 (A0), IC3.16 (A1), IC3.17 (A2), IC4.10 (VSS), IC4.16 (A1), IC4.17 (A2), J1.6, J2.1, J3.4, J4.4, S1.3 (COMM_1), S1.4 (COMM_2), S2.3 (COMM_1), S2.4 (COMM_2), S3.3 (COMM_1), S3.4 (COMM_2), S4.3 (COMM_1), S4.4 (COMM_2), S5.3 (COMM_1), S5.4 (COMM_2), S6.3 (COMM_1), S6.4 (COMM_2), S7.3 (COMM_1), S7.4 (COMM_2), S8.3 (COMM_1), S8.4 (COMM_2), S9.3 (COMM_1), S9.4 (COMM_2), S10.3 (COMM_1), S10.4 (COMM_2), S11.3 (COMM_1), S11.4 (COMM_2), S12.3 (COMM_1), S12.4 (COMM_2), S13.3 (COMM_1), S13.4 (COMM_2), S14.3 (COMM_1), S14.4 (COMM_2), S15.3 (COMM_1), S15.4 (COMM_2), S16.3 (COMM_1), S16.4 (COMM_2), S17.3 (COMM_1), S17.4 (COMM_2), S18.3 (COMM_1), S18.4 (COMM_2), S19.3 (COMM_1), S19.4 (COMM_2), SW1.C, U1.3 (GND), U1.5 (GND), U1.21 (GND), U2.4 (GND), U2.9 (GND), U3.4 (GND), U3.9 (GND)
GPIO_INT: IC3.20 (INTA), IC4.20 (INTA)
LED_ADSR: IC3.26 (GPA5), R6.1
LED_CUTOFF: IC3.23 (GPA2), R9.1
LED_LFO1: IC3.28 (GPA7), R4.1
LED_LFO2: IC3.27 (GPA6), R5.1
LED_LFO2MOD: IC3.8 (GPB7), R13.1
LED_LOAD: U1.13 (PB1), U2.12 (LOAD), U3.12 (LOAD)
LED_MASTERLEVEL: IC3.21 (GPA0), R11.1
LED_MODWH: R18.1, U1.12 (PB0)
LED_NOTE: IC3.24 (GPA3), R8.1
LED_RESONANCE: IC3.22 (GPA1), R10.1
LED_UNIDETUNE: IC3.7 (GPB6), R12.1
LED_VELOCITY: IC3.25 (GPA4), R7.1
unnamed: D49.2 (A), R4.2
unnamed: D50.2 (A), R5.2
unnamed: D51.2 (A), R6.2
unnamed: D52.2 (A), R7.2
unnamed: D53.2 (A), R8.2
unnamed: D54.2 (A), R9.2
unnamed: D55.2 (A), R10.2
unnamed: D56.2 (A), R11.2
unnamed: D57.2 (A), R12.2
unnamed: D58.2 (A), R13.2
unnamed: D59.2 (A), R18.2
unnamed: IC1.4 (RXD), IC2.2 (RXCAN)
unnamed: IC1.1 (TXD), IC2.1 (TXCAN)
unnamed: C2.2, IC2.9 (OSC1), Y1.1
unnamed: C1.2, IC2.8 (OSC2), Y1.2
unnamed: IC2.19 (~RESET), R1.2
unnamed: C11.1, U1.20 (AREF)
unnamed: C6.1, U1.7 (XTAL1/PB6), Y2.2
unnamed: C7.1, U1.8 (XTAL2/PB7), Y2.1
unnamed: U2.24 (DOUT), U3.1 (DIN)
unnamed: R2.2, U2.18 (ISET)
unnamed: R3.2, U3.18 (ISET)
PB_BIAS: IC4.4 (GPB3), S4.2 (NO_1), S4.5 (NO_2)
PB_CHAOS: IC4.5 (GPB4), S5.2 (NO_1), S5.5 (NO_2)
PB_CLEARROUTE: IC3.6 (GPB5), S19.2 (NO_1), S19.5 (NO_2)
PB_FOLDS: IC4.3 (GPB2), S3.2 (NO_1), S3.5 (NO_2)
PB_GLOBAL_DEST: IC3.1 (GPB0), S15.2 (NO_1), S15.5 (NO_2)
PB_LEVEL: IC4.7 (GPB6), S7.2 (NO_1), S7.5 (NO_2)
PB_OSC1: IC4.21 (GPA0), S8.2 (NO_1), S8.5 (NO_2)
PB_OSC2: IC4.22 (GPA1), S9.2 (NO_1), S9.5 (NO_2)
PB_OSC3: IC4.23 (GPA2), S10.2 (NO_1), S10.5 (NO_2)
PB_OSC4: IC4.24 (GPA3), S11.2 (NO_1), S11.5 (NO_2)
PB_OSC5: IC4.25 (GPA4), S12.2 (NO_1), S12.5 (NO_2)
PB_OSC6: IC4.26 (GPA5), S13.2 (NO_1), S13.5 (NO_2)
PB_PITCH: IC4.1 (GPB0), S1.2 (NO_1), S1.5 (NO_2)
PB_PULSE: IC4.2 (GPB1), S2.2 (NO_1), S2.5 (NO_2)
PB_RATE: IC4.6 (GPB5), S6.2 (NO_1), S6.5 (NO_2)
PB_ROUTE_DEC: IC3.4 (GPB3), S17.2 (NO_1), S17.5 (NO_2)
PB_ROUTE_INC: IC3.3 (GPB2), S16.2 (NO_1), S16.5 (NO_2)
PB_SAVEROUTE: IC3.5 (GPB4), S18.2 (NO_1), S18.5 (NO_2)
PB_SOURCE_SEL: IC3.2 (GPB1), S14.2 (NO_1), S14.5 (NO_2)
RESET: J1.5, R24.2, U1.29 (~RESET/PC6)
Row_1: D1.1 (K), D2.1 (K), D3.1 (K), D4.1 (K), D5.1 (K), D6.1 (K), D7.1 (K), D8.1 (K), U3.2 (DIG_0)
Row_2: D9.1 (K), D10.1 (K), D11.1 (K), D12.1 (K), D13.1 (K), D14.1 (K), D15.1 (K), D16.1 (K), U3.11 (DIG_1)
Row_3: D17.1 (K), D18.1 (K), D19.1 (K), D20.1 (K), D21.1 (K), D22.1 (K), D23.1 (K), D24.1 (K), U3.6 (DIG_2)
Row_4: D25.1 (K), D26.1 (K), D27.1 (K), D28.1 (K), D29.1 (K), D30.1 (K), D31.1 (K), D32.1 (K), U3.7 (DIG_3)
Row_5: D33.1 (K), D34.1 (K), D35.1 (K), D36.1 (K), D37.1 (K), D38.1 (K), D39.1 (K), D40.1 (K), U3.3 (DIG_4)
Row_6: D41.1 (K), D42.1 (K), D43.1 (K), D44.1 (K), D45.1 (K), D46.1 (K), D47.1 (K), D48.1 (K), U3.10 (DIG_5)
SCL: IC3.12 (SCL), IC4.12 (SCL), R17.2, U1.28 (PC5)
SDA: IC3.13 (SDA), IC4.13 (SDA), R16.2, U1.27 (PC4)
SERIAL_RX: J2.2, U1.30 (PD0)
SERIAL_TX: J2.3, U1.31 (PD1)
Seg_A: DS1.7 (ANODE_A), DS2.11, U2.14 (SEG_A)
Seg_B: DS1.8 (ANODE_B), DS2.7, U2.16 (SEG_B)
Seg_C: DS1.3 (ANODE_C), DS2.4, U2.20 (SEG_C)
Seg_D: DS1.2 (ANODE_D), DS2.2, U2.23 (SEG_D)
Seg_DP: DS1.5 (ANODE_DP), DS2.3, U2.22 (SEG_DP)
Seg_E: DS1.1 (ANODE_E), DS2.1, U2.21 (SEG_E)
Seg_F: DS1.10 (ANODE_F), DS2.10, U2.15 (SEG_F)
Seg_G: DS1.4 (ANODE_G), DS2.5, U2.17 (SEG_G)

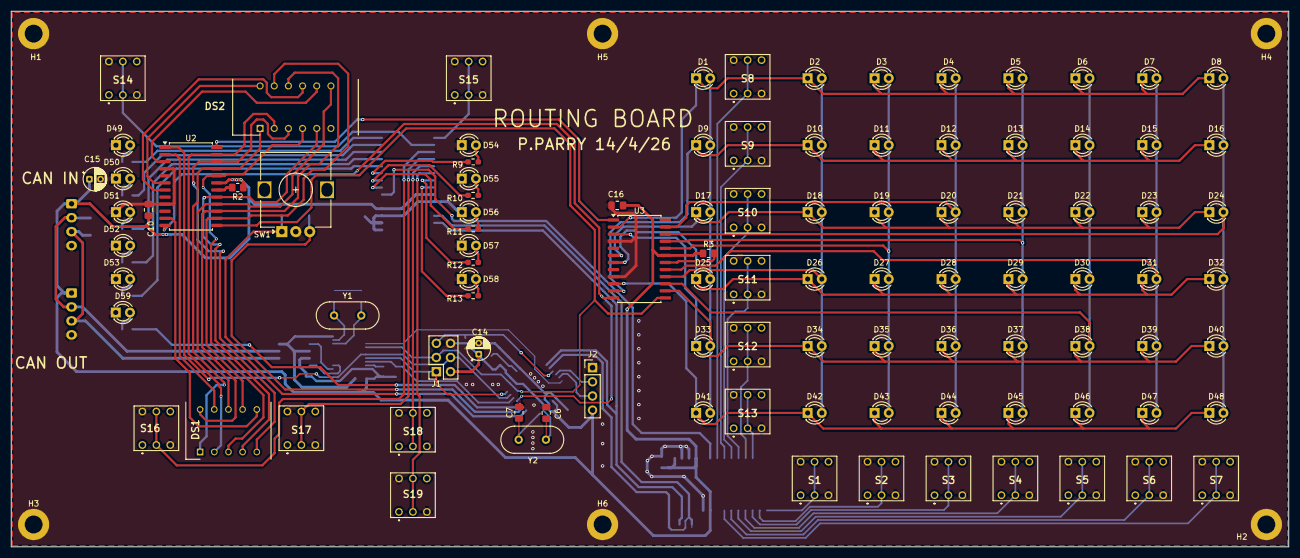
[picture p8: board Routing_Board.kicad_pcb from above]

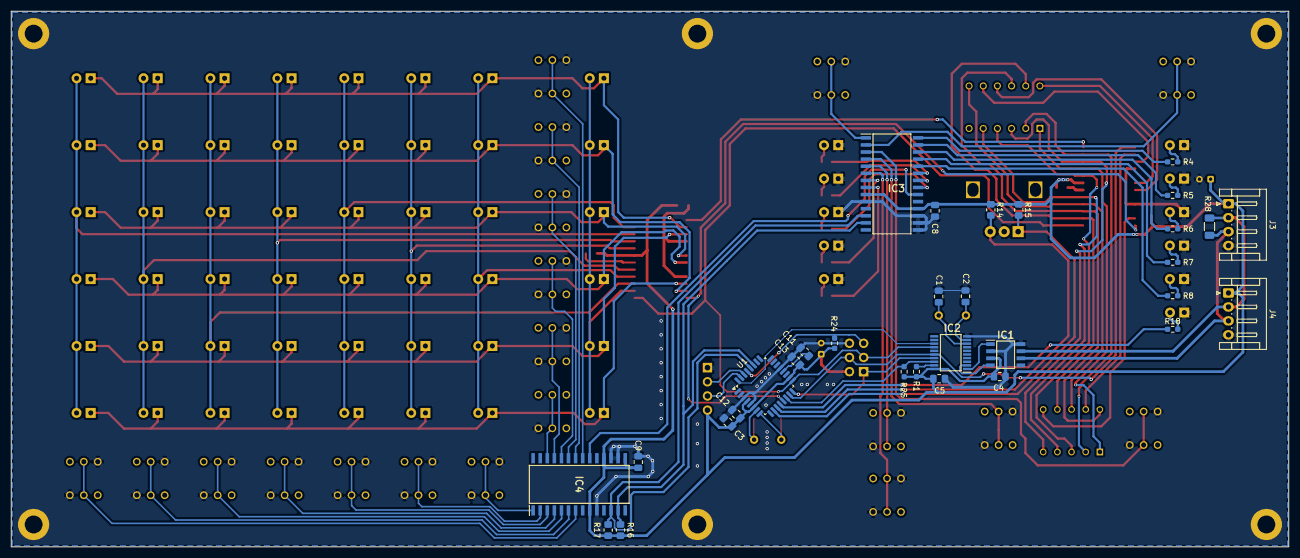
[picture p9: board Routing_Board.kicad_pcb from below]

Board: 2 copper layers, 229.0 x 96.0 mm, 137 parts (31 on the bottom side), 97 nets.

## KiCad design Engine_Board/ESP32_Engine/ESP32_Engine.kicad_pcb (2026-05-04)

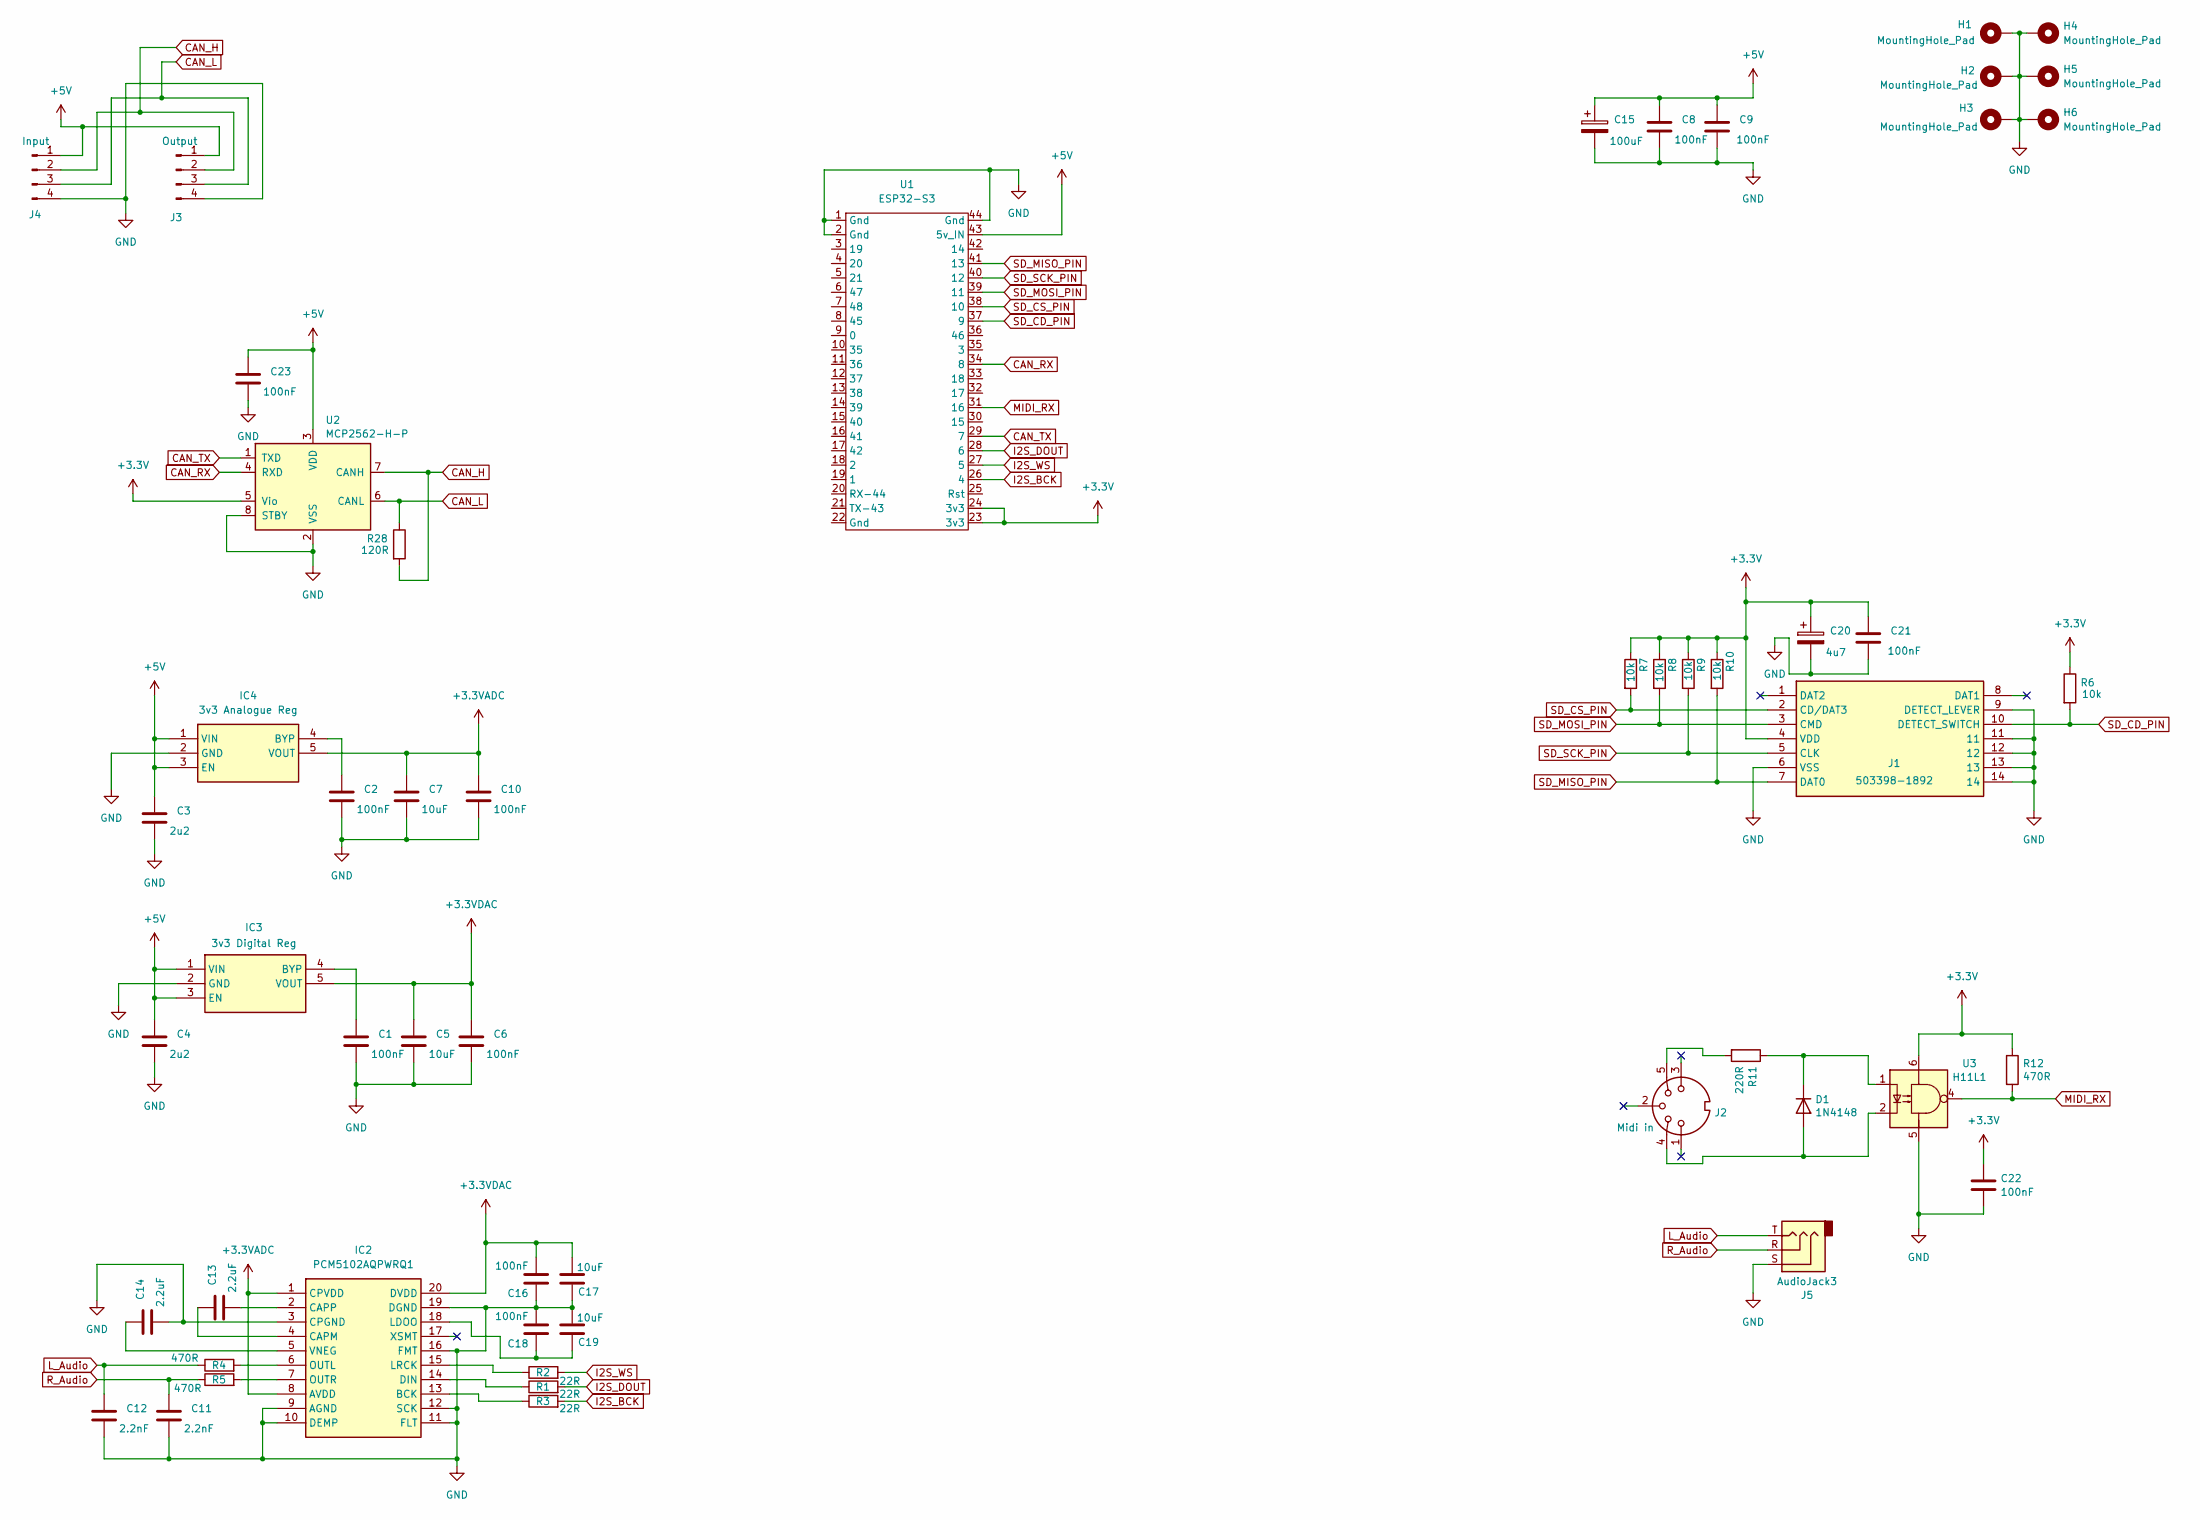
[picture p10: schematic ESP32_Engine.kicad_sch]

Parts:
C1, C2, C6, C10, C16, C18, C23: 100nF; C_0603_1608Metric_Pad1.08x0.95mm_HandSolder
C3, C4: 2u2; C_0805_2012Metric_Pad1.18x1.45mm_HandSolder
C5, C7, C17, C19: 10uF; C_0805_2012Metric_Pad1.18x1.45mm_HandSolder
C8, C9, C21: 100nF; C_0805_2012Metric_Pad1.18x1.45mm_HandSolder
C11, C12: 2.2nF; C_0603_1608Metric_Pad1.08x0.95mm_HandSolder
C13, C14: 2.2uF; C_0805_2012Metric_Pad1.18x1.45mm_HandSolder
C15: 100uF; CP_Radial_D4.0mm_P2.00mm
C20: 4u7; CP_Radial_D4.0mm_P2.00mm
C22: 100nF; C_0805_2012Metric
D1: 1N4148; D_MELF
H1, H2, H3, H4, H5, H6: MountingHole_Pad; MountingHole_3.2mm_M3_DIN965_Pad
IC2: PCM5102AQPWRQ1; SOP65P640X120-20N; Mouser Part Number 595-PCM5102AQPWRQ1
IC3: 3v3 Digital Reg; SOT95P280X100-5N; Mouser Part Number 998-MIC5323-3.3YD5TR
IC4: 3v3 Analogue Reg; SOT95P280X100-5N; Mouser Part Number 998-MIC5323-3.3YD5TR
J1: 503398-1892; 5033981892; Mouser Part Number 538-503398-1892
J2: Midi in; Midi_Socket
J3: Output; JST_EH_S4B-EH_1x04_P2.50mm_Horizontal
J4: Input; JST_EH_S4B-EH_1x04_P2.50mm_Horizontal
J5: AudioJack3; Jack_3.5mm_CUI_SJ1-3533NG_Horizontal
R1, R2, R3: 22R; R_0603_1608Metric_Pad0.98x0.95mm_HandSolder
R4, R5, R12: 470R; R_0603_1608Metric_Pad0.98x0.95mm_HandSolder
R6, R7, R8, R9, R10: 10k; R_0603_1608Metric_Pad0.98x0.95mm_HandSolder
R11: 220R; R_0603_1608Metric_Pad0.98x0.95mm_HandSolder
R28: 120R; R_0603_1608Metric_Pad0.98x0.95mm_HandSolder
U1: ESP32-S3; ESP32_S3
U2: MCP2562-H-P; DIP-8_W7.62mm
U3: H11L1; DIP-6_W7.62mm_SMDSocket_SmallPads

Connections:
+3.3V: C20.1, C21.1, C22.1, J1.4 (VDD), R6.1, R7.1, R8.1, R9.1, R10.1, R12.1, U1.23 (3v3), U1.24 (3v3), U2.5 (Vio), U3.6
+3.3VADC: C7.1, C10.1, IC2.1 (CPVDD), IC2.8 (AVDD), IC4.5 (VOUT)
+3.3VDAC: C5.1, C6.1, C16.2, C17.2, IC2.20 (DVDD), IC3.5 (VOUT)
+5V: C3.1, C4.1, C8.1, C9.1, C15.1, C23.1, IC3.1 (VIN), IC3.3 (EN), IC4.1 (VIN), IC4.3 (EN), J3.1, J4.1, U1.43 (5v_IN), U2.3 (VDD)
CAN_H: J3.2, J4.2, R28.2, U2.7 (CANH)
CAN_L: J3.3, J4.3, R28.1, U2.6 (CANL)
CAN_RX: U1.34 (8), U2.4 (RXD)
CAN_TX: U1.29 (7), U2.1 (TXD)
GND: C1.2, C2.2, C3.2, C4.2, C5.2, C6.2, C7.2, C8.2, C9.2, C10.2, C11.2, C12.2, C14.2, C15.2, C16.1, C17.1, C18.2, C19.2, C20.2, C21.2, C22.2, C23.2, H1.1, H2.1, H3.1, H4.1, H5.1, H6.1, IC2.3 (CPGND), IC2.9 (AGND), IC2.10 (DEMP), IC2.11 (FLT), IC2.12 (SCK), IC2.16 (FMT), IC2.19 (DGND), IC3.2 (GND), IC4.2 (GND), J1.6 (VSS), J1.9 (DETECT_LEVER), J1.11, J1.12, J1.13, J1.14, J2.6, J2.7, J3.4, J4.4, J5.S, U1.1 (Gnd), U1.2 (Gnd), U1.44 (Gnd), U2.2 (VSS), U2.8 (STBY), U3.5
I2S_BCK: R3.2, U1.26 (4)
I2S_DOUT: R1.2, U1.28 (6)
I2S_WS: R2.2, U1.27 (5)
L_Audio: C12.1, J5.T, R4.1
MIDI_RX: R12.2, U1.31 (16), U3.4
unnamed: D1.2 (A), J2.4, U3.2
unnamed: D1.1 (K), R11.1, U3.1
unnamed: IC2.13 (BCK), R3.1
unnamed: C13.1, IC2.4 (CAPM)
unnamed: C13.2, IC2.2 (CAPP)
unnamed: IC2.14 (DIN), R1.1
unnamed: C18.1, C19.1, IC2.18 (LDOO)
unnamed: IC2.15 (LRCK), R2.1
unnamed: IC2.6 (OUTL), R4.2
unnamed: IC2.7 (OUTR), R5.2
unnamed: C14.1, IC2.5 (VNEG)
unnamed: C1.1, IC3.4 (BYP)
unnamed: C2.1, IC4.4 (BYP)
unnamed: J2.5, R11.2
R_Audio: C11.1, J5.R, R5.1
SD_CD_PIN: J1.10 (DETECT_SWITCH), R6.2, U1.37 (9)
SD_CS_PIN: J1.2 (CD/DAT3), R7.2, U1.38 (10)
SD_MISO_PIN: J1.7 (DAT0), R10.2, U1.41 (13)
SD_MOSI_PIN: J1.3 (CMD), R8.2, U1.39 (11)
SD_SCK_PIN: J1.5 (CLK), R9.2, U1.40 (12)

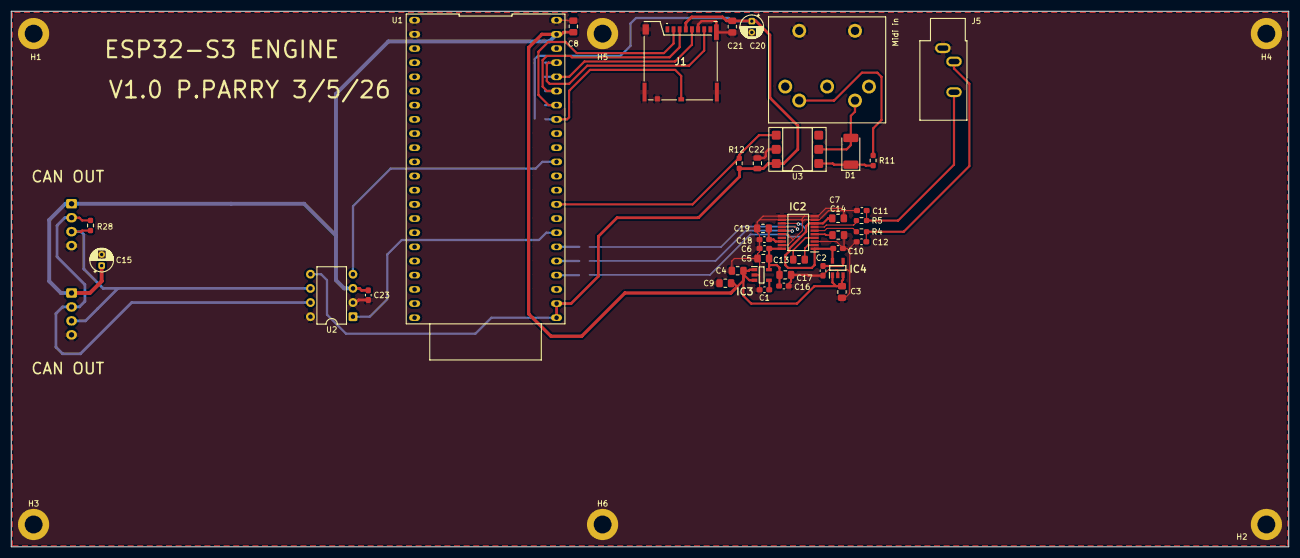
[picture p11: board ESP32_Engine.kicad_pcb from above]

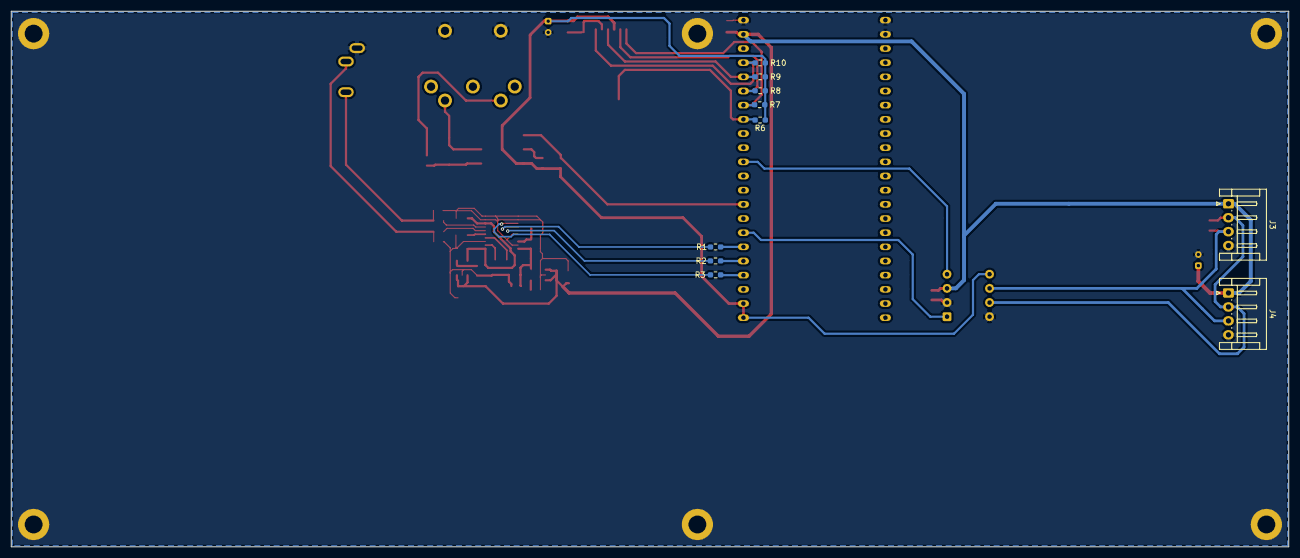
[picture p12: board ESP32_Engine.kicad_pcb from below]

Board: 2 copper layers, 229.0 x 96.0 mm, 54 parts (10 on the bottom side), 34 nets.

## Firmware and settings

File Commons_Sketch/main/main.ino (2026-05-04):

#include "ADC.h"
#include "IO.h"
#include "Board.h"
#include "CAN_Comm.h"
#include "param_map.h"

// ================================================================
// main.ino — Commons PCB, ATmega328p
// Filter / Ring Mod / LFO / ADSR / Unison controls
// ================================================================

// ----------------------------------------------------------------
// Debug modes — comment out both for production
//
// DEBUG_MODE     : button press / LED mapping
// DEBUG_ADC_CAL  : ADC raw value reporting (CAN suppressed)
//                  Use DEBUG_ADC_CHANNEL=-1 for all channels,
//                  or a specific channel number to focus.
//                  Run this to calibrate CH5/CH10/CH15 switch ranges.
// ----------------------------------------------------------------
//#define DEBUG_MODE
//#define DEBUG_ADC_CAL

#define DEBUG_ADC_CHANNEL    -1
#define CAL_PRINT_THRESHOLD  15

// ================================================================
// DEBUG_ADC_CAL
// ================================================================
#ifdef DEBUG_ADC_CAL

static const char * const chLabel[16] =
{
    "Unison Detune    ",  //  0
    "ADSR Release     ",  //  1
    "ADSR Sustain     ",  //  2
    "ADSR Decay       ",  //  3
    "ADSR Attack      ",  //  4
    "LFO1 Waveform    ",  //  5  *** calibrate switch ***
    "LFO1 Delay       ",  //  6
    "LFO1 Rate        ",  //  7
    "LFO2 Rate        ",  //  8
    "LFO2 Delay       ",  //  9
    "LFO2 Waveform    ",  // 10  *** calibrate switch ***
    "Env/Track Amount ",  // 11
    "Filter Resonance ",  // 12
    "Filter Frequency ",  // 13
    "Ring Mod Level   ",  // 14
    "Ring Mod Pairs   ",  // 15  *** calibrate switch ***
};

static uint16_t calLastPrinted[16];
static void calInit() { for (uint8_t i=0;i<16;i++) calLastPrinted[i]=9999; }

static void calPrintChannel(uint8_t ch, uint16_t raw)
{
    Serial.print(F("CH"));
    if (ch < 10) Serial.print('0');
    Serial.print(ch);
    Serial.print(F("  ["));
    Serial.print(chLabel[ch]);
    Serial.print(F("]  raw="));
    if (raw < 1000) Serial.print(' ');
    if (raw  < 100) Serial.print(' ');
    if (raw   < 10) Serial.print(' ');
    Serial.print(raw);
    Serial.print(F("  ("));
    Serial.print((raw * 100UL) / 1023);
    Serial.println(F("%)"));
}
#endif // DEBUG_ADC_CAL

// ================================================================
// DEBUG_MODE (button / LED mapping)
// ================================================================
#ifdef DEBUG_MODE

static const char * const btnNames[BTN_COUNT] =
{
    "FILTER_MODE", "MOD_MUTE", "RING_ENABLE",
    "LFO2_TRIG", "ENV_TRACK", "POLY_MODE", "LFO1_TRIG"
};

static void debugPrintIC3(uint16_t ledWord)
{
    uint8_t gpa = ledWord & 0xFF;
    uint8_t gpb = ledWord >> 8;
    Serial.print(F("  IC3: 0x"));
    if (ledWord < 0x1000) Serial.print('0');
    if (ledWord < 0x0100) Serial.print('0');
    if (ledWord < 0x0010) Serial.print('0');
    Serial.print(ledWord, HEX);
    Serial.print(F("  GPA:"));
    for (int8_t i=7;i>=0;i--) Serial.print((gpa>>i)&1);
    Serial.print(F("  GPB:"));
    for (int8_t i=7;i>=0;i--) Serial.print((gpb>>i)&1);
    Serial.println();
}

static void debugPrintButton(Button_t btn)
{
    const BTN_Map_t *e = &btnMap[btn];
    Serial.println(F("----"));
    Serial.print(F("BTN: ")); Serial.println(btnNames[btn]);
    switch (e->mode)
    {
        case BTN_MODE_TOGGLE:
            Serial.print(F("  TOGGLE state: "));
            Serial.println(CAN_GetToggleState(btn) ? F("ON (Env)") : F("OFF (Track)"));
            break;
        case BTN_MODE_MOMENTARY:
            Serial.println(F("  MOMENTARY"));
            break;
        case BTN_MODE_CYCLER:
        {
            uint8_t s = CAN_GetCyclerState(btn);
            Serial.print(F("  CYCLER state: ")); Serial.print(s);
            if (btn == BTN_FILTER_MODE)
            {
                if (s==0) Serial.println(F(" (Lowpass)"));
                else if (s==1) Serial.println(F(" (Bandpass)"));
                else Serial.println(F(" (Highpass)"));
            }
            else if (btn == BTN_POLY_MODE)
            {
                if (s==0) Serial.println(F(" (Poly)"));
                else if (s==1) Serial.println(F(" (Duo)"));
                else Serial.println(F(" (Unison)"));
            }
            break;
        }
        default: break;
    }
    debugPrintIC3(CAN_GetLEDs());
}
#endif // DEBUG_MODE

// ================================================================
// setup / loop
// ================================================================

void setup()
{
    Serial.begin(115200);

    Board_Init();
    ADC_Init();
    IO_Init();

    if (!CAN_Init())
    {
        Serial.println(F("CAN init failed"));
        while (true) { IO_SetLEDs(0xFFFF); delay(300); IO_SetLEDs(0x0000); delay(300); }
    }

    Board_SendAnnouncement();

    Serial.print(F("CAN init OK  Board ID="));
    Serial.println(Board_GetID());

#ifdef DEBUG_ADC_CAL
    calInit();
    Serial.println(F("ADC CAL MODE (CAN suppressed)"));
    Serial.println(F("Calibrate CH5/CH10/CH15 switch positions."));
    Serial.println(F("Step through each position, note stable raw values."));
    Serial.println(F("Update lfoWaveformRanges[] and ringModPairsRanges[]"));
    Serial.println(F("in CAN_Comm.cpp with midpoint-based windows."));
#endif

    IO_SetLEDs(CAN_GetLEDs());
}

void loop()
{
    ADC_Task();
    IO_Task();

#ifndef DEBUG_ADC_CAL
    CAN_Task();
#endif

    // ================================================================
    // ADC calibration mode
    // ================================================================
#ifdef DEBUG_ADC_CAL

    for (uint8_t ch = 0; ch < 16; ch++)
    {
        if (DEBUG_ADC_CHANNEL >= 0 && ch != (uint8_t)DEBUG_ADC_CHANNEL)
            continue;

        uint16_t raw = ADC_GetChannelValue(ch);
        int32_t diff = (int32_t)raw - (int32_t)calLastPrinted[ch];
        if (diff < 0) diff = -diff;
        if (diff >= CAL_PRINT_THRESHOLD)
        {
            calLastPrinted[ch] = raw;
            calPrintChannel(ch, raw);
        }
    }

#else
    // ================================================================
    // Normal operation
    // ================================================================

    // Continuous ADC channels (all except ranged switch channels)
    for (uint8_t ch = 0; ch < 16; ch++)
    {
        if (ch == 5 || ch == 10 || ch == 15) continue; // handled by CAN_ProcessRangedChannels
        if (ADC_GetChannelChanged(ch))
            CAN_ProcessADC(ch, ADC_GetChannelValue(ch));
    }

    // Switch channels — polled every loop for settle timer
    CAN_ProcessRangedChannels();

    // Buttons
    for (uint8_t b = 0; b < BTN_COUNT; b++)
    {
        if (IO_IsButtonPressed((Button_t)b))
        {
            CAN_ProcessButton((Button_t)b);
#ifdef DEBUG_MODE
            IO_SetLEDs(CAN_GetLEDs());
            debugPrintButton((Button_t)b);
#endif
        }
    }

    IO_SetLEDs(CAN_GetLEDs());

#endif // DEBUG_ADC_CAL
}

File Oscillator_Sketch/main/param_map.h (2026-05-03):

#pragma once

// ================================================================
// param_map.h
// The single "truth table" for all hardware → CAN mappings.
// Edit this file to change what any knob, button, or LED does.
// ================================================================

#include "synth_params.h"
#include "IO.h"
#include <stdint.h>

// ================================================================
// Encoding types
// ================================================================
typedef enum
{
    // 10-bit → 0-65535. ESP32 decodes linearly.
    ENCODE_LINEAR,

    // 10-bit → 0-65535. ESP32 decodes exponentially (freq/time).
    ENCODE_EXP,

    // Resistor-ladder rotary switch. Raw ADC value is matched
    // against a StepRange_t table (defined in CAN_Comm.cpp).
    // Sends the canValue of the matched window after a settle period.
    // Readings that fall between windows are discarded (transition).
    ENCODE_RANGED,

    // Log-pot Detune with zero-band and piecewise linear compensation.
    // Hardware centre = DETUNE_RAW_CENTRE (≈300 for A-taper pot).
    // Raw inside zero band → sends exact 32767 (= 0 cents on ESP32).
    // Raw outside zero band → piecewise linear both sides of centre.
    // LED behaviour: solid in band, flashing outside (rate ∝ distance).
    ENCODE_DETUNE,

} EncodeType_t;

// ================================================================
// Resistor ladder step range
// One entry per switch position.
// adcMin/adcMax: ADC window boundaries (derived from measured values
// by taking midpoints between adjacent positions).
// canValue: the integer value sent in the CAN frame for this position.
// ================================================================
typedef struct
{
    uint16_t adcMin;
    uint16_t adcMax;
    uint16_t canValue;
} StepRange_t;

// ================================================================
// Detune zero band config
//
// Pot is LINEAR. With ADC_SETTLE_US=20 the centre reads ~505-515.
// Zero band brackets this so the user has a comfortable dead zone
// at 12 o'clock that sends exactly 32767 (= 0 cents on ESP32).
// Adjust LOW/HIGH if your hardware centre sits outside this range.
//
// ENCODE_DETUNE uses simple linear encoding (0→0, 1023→65535)
// outside the band — no log compensation needed.
// ================================================================
#define DETUNE_ZERO_BAND_LOW   480   // lower edge of zero band
#define DETUNE_ZERO_BAND_HIGH  545   // upper edge of zero band

// Flash rate at band edge and at full deflection (milliseconds).
#define DETUNE_FLASH_SLOW_MS   800
#define DETUNE_FLASH_FAST_MS    60

// Hold duration (ms) to disable an active modifier.
// Pressing and holding a modifier button for this long sends the disable
// CAN message and returns the modifier to the off state.
#define MODIFIER_HOLD_MS          2000

// Pot catch tuning
// CATCH_WINDOW: if the pot is already within this many ADC counts of the
// catch target when catch is activated, skip catch entirely.
#define CATCH_WINDOW              50   // ~5% of range
// CATCH_MOVE_THRESHOLD: release catch once the pot has moved this far from
// the position it was at when catch was activated, bounding any discontinuity
// to this distance rather than the full gap between the two pot positions.
#define CATCH_MOVE_THRESHOLD      80   // ~8% of range

// ================================================================
// Switch settle time (ENCODE_RANGED channels)
// Reading must remain within the same window for this many ms
// before a CAN message is sent. Filters zero-drop transients
// between switch contacts and debounces resistor-ladder glitches.
// ================================================================
#define SWITCH_SETTLE_MS          40

// ================================================================
// A single CAN parameter target + its encoding
// ================================================================
typedef struct
{
    uint8_t      canId;
    uint8_t      target;
    uint8_t      param;
    EncodeType_t encoding;
    uint8_t      steps;     // unused for ENCODE_LINEAR/EXP/DETUNE
} ParamDef_t;

// ================================================================
// ADC channel entry
// shiftBtn: -1 = single function
//           Button_t = MODIFIER/TOGGLE button index
//           EXTRA_BTN_A6/A7 = local extra button
// ================================================================
typedef struct
{
    ParamDef_t primary;
    ParamDef_t secondary;
    int8_t     shiftBtn;
} ADC_Map_t;

// Extra local-only shift button sentinels (> BTN_COUNT, fits int8_t)
#define EXTRA_BTN_A6   100
#define EXTRA_BTN_A7   101
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

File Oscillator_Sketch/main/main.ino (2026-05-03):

#include "ADC.h"
#include "IO.h"
#include "Board.h"
#include "CAN_Comm.h"
#include "param_map.h"

// ================================================================
// main.ino  —  Oscillator board, ATmega328p
// ================================================================

// ----------------------------------------------------------------
// Debug modes — comment out both for production
//
// DEBUG_MODE     : button press / LED mapping
// DEBUG_ADC_CAL  : ADC raw value reporting (CAN suppressed)
//                  Set DEBUG_ADC_CHANNEL to a channel number to
//                  watch one channel, or -1 for all.
// ----------------------------------------------------------------
// #define DEBUG_MODE
// #define DEBUG_ADC_CAL

#define DEBUG_ADC_CHANNEL    -1
#define CAL_PRINT_THRESHOLD  15
#define CAL_DETUNE_ZERO_LOW  DETUNE_ZERO_BAND_LOW
#define CAL_DETUNE_ZERO_HIGH DETUNE_ZERO_BAND_HIGH

// ================================================================
// DEBUG_ADC_CAL
// ================================================================
#ifdef DEBUG_ADC_CAL

static const char * const chLabel[16] =
{
    "OSC1 ChaosR      ",  //  0
    "OSC1 PulseWidth  ",  //  1
    "OSC1 Fold/Bias   ",  //  2
    "OSC1 SH Rate/Rng ",  //  3
    "OSC1 Level       ",  //  4
    "OSC1 Waveform    ",  //  5
    "OSC1 Detune/Phase",  //  6
    "OSC1 Octave      ",  //  7
    "OSC2 Waveform    ",  //  8
    "OSC2 Octave      ",  //  9
    "OSC2 Detune/Phase",  // 10
    "OSC2 PulseWidth  ",  // 11
    "OSC2 ChaosR      ",  // 12
    "OSC2 Fold/Bias   ",  // 13
    "OSC2 SH Rate/Rng ",  // 14
    "OSC2 Level       ",  // 15
};

static uint16_t calLastPrinted[16];

static void calInit()
{
    for (uint8_t i = 0; i < 16; i++) calLastPrinted[i] = 9999;
}

static void calPrintChannel(uint8_t ch, uint16_t raw)
{
    Serial.print(F("CH"));
    if (ch < 10) Serial.print('0');
    Serial.print(ch);
    Serial.print(F("  ["));
    Serial.print(chLabel[ch]);
    Serial.print(F("]  raw="));
    if (raw < 1000) Serial.print(' ');
    if (raw <  100) Serial.print(' ');
    if (raw <   10) Serial.print(' ');
    Serial.print(raw);

    int16_t dist = (int16_t)raw - 512;
    Serial.print(F("  ("));
    if (dist >= 0) Serial.print('+');
    Serial.print(dist);
    Serial.print(F(")  "));

    if (ch == 6 || ch == 10)
    {
        if (raw >= CAL_DETUNE_ZERO_LOW && raw <= CAL_DETUNE_ZERO_HIGH)
        {
            Serial.print(F("[IN ZERO BAND] LED=SOLID"));
        }
        else
        {
            uint16_t edge = (raw < CAL_DETUNE_ZERO_LOW)
                            ? (CAL_DETUNE_ZERO_LOW - raw)
                            : (raw - CAL_DETUNE_ZERO_HIGH);
            uint32_t maxD = (raw < CAL_DETUNE_ZERO_LOW)
                            ? CAL_DETUNE_ZERO_LOW
                            : (1023 - CAL_DETUNE_ZERO_HIGH);
            uint32_t period = DETUNE_FLASH_SLOW_MS -
                              ((uint32_t)edge * (DETUNE_FLASH_SLOW_MS - DETUNE_FLASH_FAST_MS)) / maxD;
            Serial.print(F("flash ~")); Serial.print(period); Serial.print(F("ms"));
        }
    }

    Serial.print(F("  (")); Serial.print((raw * 100UL) / 1023); Serial.println(F("%)"));
}

#endif // DEBUG_ADC_CAL

// ================================================================
// DEBUG_MODE (button / LED mapping)
// ================================================================
#ifdef DEBUG_MODE

static const char * const btnNames[BTN_COUNT] =
{
    "OSC1_SH", "OSC1_FOLD", "OSC1_CLONE", "OSC1_SOLO", "OSC1_SYNC",
    "OSC2_SYNC", "OSC2_SOLO", "OSC2_CLONE", "OSC2_FOLD", "OSC2_SH"
};

static void debugPrintIC3(uint16_t ledWord)
{
    uint8_t gpa = ledWord & 0xFF;
    uint8_t gpb = ledWord >> 8;
    Serial.print(F("  IC3: 0x"));
    if (ledWord < 0x1000) Serial.print('0');
    if (ledWord < 0x0100) Serial.print('0');
    if (ledWord < 0x0010) Serial.print('0');
    Serial.print(ledWord, HEX);
    Serial.print(F("  GPA:"));
    for (int8_t i = 7; i >= 0; i--) Serial.print((gpa >> i) & 1);
    Serial.print(F("  GPB:"));
    for (int8_t i = 7; i >= 0; i--) Serial.print((gpb >> i) & 1);
    Serial.println();
}

static void debugPrintButton(Button_t btn)
{
    const BTN_Map_t *e = &btnMap[btn];
    Serial.println(F("----"));
    Serial.print(F("BTN: ")); Serial.println(btnNames[btn]);
    switch (e->mode)
    {
        case BTN_MODE_TOGGLE:
            Serial.print(F("  TOGGLE state: "));
            Serial.println(CAN_GetToggleState(btn) ? F("ON") : F("OFF"));
            break;
        case BTN_MODE_MOMENTARY:
            Serial.println(F("  MOMENTARY"));
            break;
        case BTN_MODE_MODIFIER:
        {
            uint8_t s = CAN_GetModifierState(btn);
            Serial.print(F("  MODIFIER state ")); Serial.print(s);
            if (s==0) Serial.println(F(" (off)"));
            else if (s==1) Serial.println(F(" (on, primary)"));
            else Serial.println(F(" (on, secondary)"));
            break;
        }
    }
    debugPrintIC3(CAN_GetLEDs());
}

static void debugPrintExtra(uint8_t which)
{
    Serial.println(F("----"));
    Serial.print(F("A")); Serial.print(which == 0 ? '6' : '7');
    Serial.print(F(" OSC")); Serial.print(which == 0 ? '1' : '2');
    Serial.print(F(": ")); Serial.println(CAN_GetExtraState(which) ? F("PHASE") : F("DETUNE"));
    debugPrintIC3(CAN_GetLEDs());
}

#endif // DEBUG_MODE

// ================================================================
// setup / loop
// ================================================================

void setup()
{
    Serial.begin(115200);

    Board_Init();
    ADC_Init();
    IO_Init();

    if (!CAN_Init())
    {
        Serial.println(F("CAN init failed"));
        while (true) { IO_SetLEDs(0xFFFF); delay(300); IO_SetLEDs(0x0000); delay(300); }
    }

    Board_SendAnnouncement();

    Serial.print(F("CAN init OK  Board ID="));
    Serial.print(Board_GetID());
    Serial.print(F("  OSC offset="));
    Serial.println(Board_GetOscOffset());

#ifdef DEBUG_ADC_CAL
    calInit();
    Serial.println(F("ADC CAL MODE (CAN suppressed)"));
    Serial.print(F("Zero band: ")); Serial.print(CAL_DETUNE_ZERO_LOW);
    Serial.print(F("-")); Serial.println(CAL_DETUNE_ZERO_HIGH);
#endif

    IO_SetLEDs(CAN_GetLEDs());
    IO_SetIC4LEDs(CAN_GetIC4LEDs());
}

void loop()
{
    ADC_Task();
    IO_Task();
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

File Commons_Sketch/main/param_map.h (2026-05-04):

#pragma once

// ================================================================
// param_map.h — Commons PCB
// The single "truth table" for all hardware → CAN mappings.
// ================================================================

#include "synth_params.h"
#include "IO.h"
#include <stdint.h>

// ================================================================
// Encoding types
// ================================================================
typedef enum
{
    ENCODE_LINEAR,   // 10-bit → 0-65535, ESP32 decodes linearly
    ENCODE_EXP,      // 10-bit → 0-65535, ESP32 decodes exponentially
    ENCODE_RANGED,   // Resistor-ladder switch — matched to StepRange_t table
    ENCODE_DETUNE,   // Unused on Commons — kept for shared CAN_Comm.cpp compat
} EncodeType_t;

// ================================================================
// Resistor ladder step range
// ================================================================
typedef struct
{
    uint16_t adcMin;
    uint16_t adcMax;
    uint16_t canValue;
} StepRange_t;

// ================================================================
// Switch settle time (ENCODE_RANGED channels)
// ================================================================
#define SWITCH_SETTLE_MS   40

// ================================================================
// Pot catch thresholds (dual-function channels, e.g. CH11 Env/Track)
//
// CATCH_WINDOW: if the pot is already within this many ADC counts of
//   the last-sent value when the button is pressed, skip catch entirely
//   and start sending immediately. Prevents any delay when the two pot
//   positions happen to be close.
//
// CATCH_MOVE_THRESHOLD: if the pot moves this many counts from its
//   position at button-press time, release the catch and start sending
//   from wherever the pot now is. The user is clearly intending to
//   adjust — a hard cross would take too long. The brief discontinuity
//   at release is bounded by this value (~8% of full range).
// ================================================================
#define CATCH_WINDOW          50   // ADC counts (~5% of range)
#define CATCH_MOVE_THRESHOLD  80   // ADC counts (~8% of range)

// ================================================================
// Detune zero band — not used on Commons PCB.
// Defined to satisfy shared CAN_Comm.cpp compilation.
// ================================================================
#define DETUNE_ZERO_BAND_LOW   480
#define DETUNE_ZERO_BAND_HIGH  545
#define DETUNE_FLASH_SLOW_MS   800
#define DETUNE_FLASH_FAST_MS    60

// ================================================================
// A single CAN parameter target + its encoding
// ================================================================
typedef struct
{
    uint8_t      canId;
    uint8_t      target;
    uint8_t      param;
    EncodeType_t encoding;
    uint8_t      steps;
} ParamDef_t;

// ================================================================
// ADC channel entry
// shiftBtn: -1 = single function, Button_t = shift button index
// No EXTRA_BTN_A6/A7 on Commons (those pins are LED outputs)
// ================================================================
typedef struct
{
    ParamDef_t primary;
    ParamDef_t secondary;
    int8_t     shiftBtn;
} ADC_Map_t;

// ================================================================
// Button modes
// ================================================================
typedef enum
{
    // Latching 2-state. Sends valueOn/valueOff. Owns local LED(s).
    BTN_MODE_TOGGLE,

    // Latching 2-state. No CAN message. Shifts pot mapping and
    // updates local indicator LEDs only. Used for Env/Track —
    // identical behaviour to A6/A7 Detune/Phase on the Oscillator board.
    BTN_MODE_LOCAL_TOGGLE,

    // Non-latching. Sends valueOn on press. No local LED.
    BTN_MODE_MOMENTARY,

    // 3-state modifier (not used on Commons — kept for shared code compat)
    BTN_MODE_MODIFIER,

    // N-state cycler: each press advances state 0→1→2→...→0.
    // Sends current state index as canValue.
    // No local LEDs — ESP32 confirms state via CAN ACK.
    BTN_MODE_CYCLER,

} BtnMode_t;
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

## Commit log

2026-05-03 Create AT238p_OSCILLATOR
    Folder for the At328p source code for the Oscillator board
2026-05-04 Replaced repo with correct structure and files
    [Commons_Board.kicad_pcb, Commons_Board.kicad_sch, ESP32_Engine.kicad_pcb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]
